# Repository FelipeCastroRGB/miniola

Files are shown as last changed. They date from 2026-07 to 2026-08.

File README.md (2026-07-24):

# Miniola 

A **Miniola** é um projeto de código aberto focado no desenvolvimento de um dispositivo de baixo custo para a inspeção de películas cinematográficas. Utilizando um sistema de transporte contínuo *sprocketless* (sem roletes dentados), o projeto tem como objetivo fornecer subsídios para a preservação do patrimônio audiovisual. Sua criação nasce da vontade de facilitar o acesso ao conteúdo de filmes em película para pesquisadores e arquivistas, além de disponibilizar um conjunto de ferramentas analíticas voltadas à compreensão do estado de conservação dos materiais.

Concebido para ser acessível e modular, o projeto possui uma estrutura cujas peças fundamentais são desenhadas para fabricação em impressoras 3D pequenas e de baixo custo. Além disso, o sistema foi pensado para atender a diferentes realidades, operando sem dependência de um hardware específico e suportando requisitos computacionais flexíveis, bem como câmeras com variadas configurações.

Estado atual de testes de hardware: 

**SBCs e PCs**

- Raspberry Pi 4 (1 GB)
- Raspberry Pi 5 (2 GB)
- Mac Mini 2012 (8 GB) - Linus Mint

**Câmeras**

- Raspberry Pi Camera Module 3
- Raspberry Pi Camera Module 2
- Raspberry Pi Camera Module 1.3
- XIMEA MQ042MG-CM

---

## Estrutura do repositorio

Arquivos principais agora ficam na **raiz do repositorio**:

- `miniola.py`: ponto de entrada principal.
- `process.py`: pos-processamento (gera MP4/ProRes a partir dos frames).
- `miniola_debug.py`: variante de depuracao (opcional)
- `requirements.txt`: dependencias Python.

---

## Guia de instalação

### 1) Dependências de Sistema

O Miniola compila extensões C++ nativas (`miniola_cv`) e utiliza o **FFMPEG** para montagem final de vídeo sincronizado com áudio (`process.py`). Em qualquer plataforma Linux (**x86_64** ou **arm64**), instale os pacotes obrigatórios:

```bash
sudo apt update
sudo apt install -y libcap-dev libgnutls28-dev python3-libcamera git python3-dev python3-venv build-essential ffmpeg libopencv-dev pkg-config
```

### 2) Clonagem

```bash
git clone https://github.com/FelipeCastroRGB/miniola.git
cd ~/miniola
```

### 3) Criação dos Diretórios de Captura

O Miniola precisa de pastas específicas para salvar os quadros temporários e os vídeos processados:
```bash
mkdir -p ~/miniola/capturas
mkdir -p ~/miniola/output
```

### 4) Ambiente Python

```bash
python3 -m venv --system-site-packages venv
source venv/bin/activate
pip install --upgrade pip setuptools wheel
pip install -r requirements.txt
pip install .
```

### 5) Instalação Específica da Câmera

O Miniola suporta diferentes modelos de câmera, com flexibilidade de hardware. Após instalar as dependências base, escolha e instale a opção de câmera que você for utilizar:

#### Opção A: Câmera Ximea (MQ042MG-CM)
Se o scanner utilizar a câmera industrial Ximea, instale o SDK oficial da fabricante (`ximea_api`). Como o pacote difere entre processadores ARM e Intel/AMD (x86_64), escolha o comando correto para a sua máquina:

- **Linux x86_64**:
> *Nota: Se o link principal de download (`kb.ximea.com`) der erro de rota/firewall, acesse a página oficial de downloads (`https://www.ximea.com/support/wiki/apis/XIMEA_Linux_Software_Package`) pelo navegador e baixe o arquivo `XIMEA_Linux_SP.tgz` para a pasta do projeto.*
```bash
# Ou via terminal tentando o servidor de atualizações beta x64:
wget -O XIMEA_Linux_SP.tgz https://updates.ximea.com/public/ximea_linux_x64_sp_beta.tgz || wget -O XIMEA_Linux_SP.tgz https://updates.ximea.com/public/ximea_linux_sp_beta.tgz
tar -xzf XIMEA_Linux_SP.tgz
cd package && ./install -cam_usb30
```

- **Linux arm64 (Raspberry Pi)**:
```bash
wget -O XIMEA_Linux_SP.tgz https://updates.ximea.com/public/ximea_linux_arm_sp_beta.tgz
tar -xzf XIMEA_Linux_SP.tgz
cd package && ./install -cam_usb30
```

#### Opção B: Raspberry Pi Camera Module 3
Se você estiver utilizando a câmera padrão do ecossistema Raspberry Pi, instale as dependências correspondentes:
```bash
pip install picamera2 python-prctl
```
> **IMPORTANTE: Aumento do Buffer USB (Obrigatório para Ximea)**
> Para que a câmera atinja a taxa máxima de quadros (FPS) em USB 3.0 sem engasgos ou perda de pacotes, você **deve** aumentar a memória do buffer USB. No Raspberry Pi OS, faça o seguinte:
>
> **Temporário (perde ao reiniciar):**
> ```bash
> echo 1000 | sudo tee /sys/module/usbcore/parameters/usbfs_memory_mb
> ```
>
> **Permanente (Recomendado):**
> Adicione o parâmetro `usbcore.usbfs_memory_mb=1000` ao final da única linha existente no arquivo `/boot/firmware/cmdline.txt`.
> ```bash
> sudo nano /boot/firmware/cmdline.txt
> ```
> *(Após editar e salvar com `Ctrl+O` > `Enter` > `Ctrl+X`, reinicie o sistema).*

### 6) Configuração do RAM Drive para captura (`tmpfs`) - Opcional

> **Nota de Hardware**: No **Raspberry Pi**, esta montagem em `tmpfs` é **muito recomendada** para gravação em cartões MicroSD. Em **MiniPCs ou computadores com SSDs de alta velocidade (NVMe/SATA)**, este passo é **opcional**, já que a gravação direta no disco costuma ser rápida o suficiente.

Se for configurar o RAM drive (`tmpfs`), edite o arquivo `fstab` (`sudo nano /etc/fstab`) e adicione ao final (lembre-se de substituir `SEU_USUARIO` pelo seu usuário real):

```text
tmpfs /home/SEU_USUARIO/miniola/capturas tmpfs defaults,noatime,size=1024M 0 0
```

Aplicar montagem:

```bash
sudo systemctl daemon-reload && sudo mount -a
```

---

## Operação

Para iniciar o sistema, ative o ambiente virtual e execute o script principal:

```bash
source venv/bin/activate
python3 miniola.py
```

---

## Pos-processamento de video (`process.py`)

Exemplos:

```bash
python3 process.py
python3 process.py --format prores
python3 process.py --format both --fps 18
python3 process.py --verify-frames
```

Por padrao, o script tenta ler frames em:

1. `./capturas`
2. `./captura` (fallback legado)

As saidas e relatorios sao gravados em `./output`.

---

## Nota de manutencao

**Resiliencia headless:** foi implementado um mock para `sys.modules["pykms"]` no topo do `miniola.py`, evitando `ModuleNotFoundError` em ambientes sem monitor fisico no Raspberry Pi OS (Bookworm).

**Fallback de motor de visao:** se `miniola_cv` falhar na compilacao (por ex., dependencias nativas ausentes), o `miniola.py` entra automaticamente em modo Python nativo. O sistema funciona, porem com menor desempenho de processamento.

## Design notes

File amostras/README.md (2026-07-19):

# Amostras e Banco de Dados Visual (`amostras/`)

Este diretório abriga o **banco de dados de imagens e fotogramas reais de película 35mm** que serve como *Ground Truth Visual* e massa de dados para testes unitários, calibração algorítmica e simulação do scanner em PC/Mac sem hardware conectado (`--camera mock`).

---

## Estrutura do Diretório

```text
amostras/
├── README.md                   # Este catálogo e guia
├── 000-template-metadata.json  # Modelo de metadados sidecar para cada imagem (.json)
├── fotogramas/                 # Quadros isolados de imagem + perfuração (PNG/JPG)
└── audio_optico/               # Amostras focadas em pistas de áudio (Densidade/Área Variável)
```

---

## O Poder dos Metadados Sidecar (`.json`) no SDD

Para que uma imagem em `amostras/fotogramas/filmcolors_1935_technicolor_01.png` seja mais do que apenas uma foto, ela deve ser acompanhada de um arquivo sidecar com o **mesmo nome e extensão `.json`** (ex.: `amostras/fotogramas/filmcolors_1935_technicolor_01.json`).

Esse JSON descreve as propriedades físicas da película original (bitola, encolhimento, tipo de áudio, estado de conservação) e, principalmente, as **coordenadas de Ground Truth (`cv_ground_truth`) para verificação automática no nosso motor C++ (`miniola_cv.cpp`) e nos testes (`tests/`)**!

---

## Catálogo de Amostras Ativas

| ID | Arquivo de Imagem | Origem / Acervo | Bitola / Furos | Áudio Óptico | Encolhimento |
| :--- | :--- | :--- | :--- | :--- | :--- |
| *(Exemplo)* `SMP-001` | `fotogramas/kodak_ks_padrao_01.png` | Teste Bancada Miniola | 35mm KS (4 furos) | Densidade Variável | 0.0% |

> **Como Alimentar**: Ao baixar exemplos de sites de referência (como o [FilmColors](https://filmcolors.org/)), escaneamentos próprios ou fotogramas de acervos parceiros, salve a imagem em `fotogramas/` e crie o `.json` correspondente usando `000-template-metadata.json`.

---

## Integração com o Driver Mock e CI
Quando o desenvolvedor executa no Mac Mini ou PC Linux:
```bash
python3 miniola.py --camera mock --sample fotogramas/filmcolors_1935_technicolor_01.png
```
O provedor `MockCameraProvider` carrega a imagem, lê o sidecar `.json`, ajusta automaticamente a ROI e transmite o fotograma em loop no dashboard Flask, permitindo validar o comportamento de detecção de perfurações e alertas *Zebra* em condições idênticas a um rolo real rodando no scanner!

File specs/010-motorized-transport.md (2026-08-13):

# SPEC-010: Integração de Transporte Motorizado (SKR Pico / TMC2209)

| Metadado | Valor |
| :--- | :--- |
| **ID da Especificação** | `SPEC-010` |
| **Status** | `Draft` |
| **Autor** | Antigravity (IA) |
| **Data de Criação** | 2026-07-26 |
| **Última Atualização** | 2026-07-26 |

---

## 1. Contexto e Objetivo
O Miniola atualmente atua como um sistema de captura passivo ou sincronizado manualmente. Para automatizar o processo de digitalização de película e garantir uma tração suave, constante e tracionada com precisão, o sistema requer a integração de um transporte motorizado. 
O hardware escolhido é a placa **BTT SKR PICO V1.0** (baseada no microcontrolador RP2040) em conjunto com drivers **TMC2209** integrados, controlando 2 motores de passo **NEMA 17 (42BYGH23-A-21DH)** para os rolos de filme, e **1 motor de passo 28BYJ-48 (modificado para bipolar)** atuando no eixo Z para controle de foco da câmera.
O objetivo desta especificação é definir como o Miniola se comunicará com esta placa via USB para controlar a velocidade e direção dos motores (X, Y e Z), mantendo a compatibilidade multi-plataforma e sem onerar a CPU que processa a visão computacional.

## 2. Requisitos Funcionais (O que o sistema deve fazer)
- `[RF-01]`: O sistema deve ser capaz de enviar comandos de Iniciar, Parar, Avançar, Recuar e Definir Velocidade para a placa controladora via porta serial (USB).
- `[RF-02]`: O dashboard web do Miniola (`miniola.py`) deve expor controles de interface (botões e sliders) para o transporte motorizado.
- `[RF-03]`: A comunicação serial deve ser não-bloqueante para evitar atrasos no loop principal de captura de quadros.
- `[RF-04]`: O sistema deve permitir a configuração da porta serial (`/dev/tty*` ou COM) via linha de comando ou arquivo de configuração.

## 3. Requisitos Não-Funcionais e Performance
- `[RNF-01]`: A taxa de captura do sensor (`fps_cam`) não deve ser afetada pela comunicação com os motores. O envio de comandos deve ocorrer em uma thread ou processo separado (ou via chamadas assíncronas de baixo custo).
- `[RNF-02]`: A placa controladora deve garantir a precisão dos pulsos (steps) em hardware real-time (no RP2040), garantindo tração suave e operação silenciosa (StealthChop no TMC2209).

---

## 4. Matriz de Impacto Multi-Plataforma

Descreva o comportamento e as restrições em cada perfil de hardware suportado pelo Miniola:

| Plataforma | Comportamento Esperado / Restrições Específicas |
| :--- | :--- |
| **Raspberry Pi 5/4 (`arm64`)** | Conexão USB-C nativa ou via GPIO UART. A porta padrão será tipicamente `/dev/ttyACM0` ou `/dev/ttyUSB0`. Mantém-se o paradigma de gravação em `tmpfs`. |
| **Mac Mini / MiniPCs (`x86_64`)** | Conexão exclusivamente via USB. A porta padrão será algo como `/dev/tty.usbmodem*` (macOS) ou `/dev/ttyACM0` (Linux). Nenhuma diferença no código lógico de controle, apenas o nome da porta. |

---

## 5. Arquitetura e Design Técnico

### 5.1. Componentes e Arquivos Modificados
- `core/motor_controller.py` **[NOVO]**: Módulo em Python responsável por instanciar a comunicação Serial e expor métodos de alto nível (`start()`, `stop()`, `set_speed()`).
- `miniola.py`: Instanciará o `motor_controller` e o passará (ou invocará) a partir do servidor web/dashboard, e conectará os endpoints da API web aos comandos do motor.
- `templates/` e `web/`: Inclusão de botões "Transporte" (Avançar/Recuar, Stop, Slider de Velocidade) no Dashboard (interface web).
- **Firmware da Placa**: A SKR Pico V1.0 rodará um firmware **C++ customizado**. Este firmware receberá comandos seriais simples via UART (via cabo USB-C) do host (RPi ou PC) e traduzirá esses comandos em sinais STEP/DIR para os drivers TMC2209 no microcontrolador RP2040 em tempo real. Adicionalmente, o firmware fará a leitura de um **Encoder Rotativo E38S6G5-600B-G24N (sinal NPN)** diretamente conectado aos seus pinos GPIO, e reportará a contagem de pulsos (posição) via porta serial de volta ao host.

### 5.2. Contratos e Estruturas de Dados

```python
# Contrato sugerido para o motor_controller.py
class MotorController:
    def __init__(self, port: str, baudrate: int = 115200):
        pass

    def connect(self) -> bool:
        pass

    def disconnect(self):
        pass

    def move_forward(self, speed: float):
        """ speed em mm/s ou rpm """
        pass

    def move_backward(self, speed: float):
        pass

    def stop(self):
        pass
```

---

## 6. Critérios de Aceitação e Plano de Verificação

### 6.1. Verificação Automatizada / Bancada (`tests/`)
- [ ] O teste unitário `test_motor_controller.py` deve mockar a porta serial e verificar se os comandos corretos (ex: strings G-code ou protocolo binário) são enviados para o buffer.
- [ ] A checagem `python3 scripts/check_specs.py` não deve apontar erros nesta spec.

### 6.2. Verificação Manual / Hardware
- [ ] Conectar a SKR Pico via USB e verificar se o Miniola consegue abrir a porta serial sem crashar.
- [ ] Clicar no botão "Avançar" no Dashboard e confirmar se o comando é transmitido e os NEMA 17 giram sem afetar o FPS da câmera.

---

## 7. Fase 2: Controle Duplo e Dinâmica de Rolos (Tração Direta)

Na Fase 2, o sistema passará a controlar 2 motores (Feed-in e Take-up) cujas velocidades físicas mudam constantemente devido à variação do diâmetro dos rolos de filme. A arquitetura escolhida (Opção A) define que:

### 7.1. Medição de Velocidade via Encoder
O hardware utilizará um **Encoder Rotativo E38S6G5-600B-G24N (600 PPR)** acoplado a um rolete por onde o filme passa. O rolete tem um **diâmetro de 26.6 mm**. O firmware da SKR Pico fará a contagem dos pulsos (usando interrupções rápidas via PIO/registradores no pino de UART) e o módulo Python converterá para velocidade linear (mm/s) através da fórmula:
`Velocidade (mm/s) = (Pulsos_Lidos / 600) * (PI * 26.6) / Tempo_Decorrido`
*Nota: Qualquer acoplamento anterior do cálculo de velocidade com a Visão Computacional (OpenCV) foi **completamente removido** da malha mecânica. Conforme definido na **SPEC-011**, a responsabilidade da velocidade é 100% do Encoder físico.*

### 7.2. Malha de Controle (PID) em Python e Aceleração (S-Curve)
A "mola matemática" será implementada em Python. O módulo `motor_controller.py` implementará um loop PID (Proporcional-Integral-Derivativo) **estritamente isolado da ótica**. Utilizando a velocidade linear calculada pelo encoder como Variável de Processo (PV). 

A velocidade alvo (Setpoint) durante a Gravação (REC) será derivada diretamente da variável global `fps_motor` (configurada via comando `mfps` no terminal), convertida para mm/s. O "sistema de playback" (sincronia estrita via `FPS_PROJECAO`) está temporariamente desabilitado para privilegiar a cadência e tração contínua da película, e a captura da câmera (`fps_cam`) agora roda totalmente desacoplada da velocidade física dos rolos.

**Aceleração (Soft Start):** Para evitar solavancos e o rompimento do filme no momento de ligar os motores, a meta do PID não sobe subitamente (degrau). Ela passa por uma rampa matemática (Smoothstep / S-Curve) durante os primeiros N segundos da captura, garantindo um "Ease-In" mecânico liso. Ao comparar com a velocidade desejada real-time, o PID ajustará a velocidade dos motores enviando comandos diferenciais (F) via porta serial para compensar o enchimento/esvaziamento dos rolos.

### 7.3. Tensão de Emergência (StallGuard)
O firmware C++ da SKR Pico fará a leitura constante do *StallGuard 4* (sensor de carga mecânica sem sensor embutido nos drivers TMC2209) medindo o *back-EMF*. Caso o filme enrosque, o pico de tensão mecânica será detectado instantaneamente pelo firmware, que cortará a corrente dos motores (emergência) e notificará o host via USB, protegendo a película de rompimento.

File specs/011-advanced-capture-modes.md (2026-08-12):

# SPEC-011: Modos de Captura Avançados (Telecine Híbrido)

| Metadado | Valor |
| :--- | :--- |
| **ID da Especificação** | `SPEC-011` |
| **Status** | `Draft` |
| **Autor** | Antigravity (IA) |
| **Data de Criação** | 2026-08-08 |
| **Última Atualização** | 2026-08-08 |

---

## 1. Contexto e Objetivo
Historicamente, a Miniola dependia da Visão Computacional (CV) tanto para o alinhamento óptico quanto para determinar a velocidade do transporte. Essa dependência ("Tight Coupling") causava instabilidades mecânicas sempre que a CV perdia um quadro.
Com a integração do Encoder Rotativo (SPEC-010), o sistema ganha consciência posicional absoluta. O objetivo desta especificação é definir a arquitetura do **Modo Telecine Contínuo Híbrido**, que separa as responsabilidades entre Mecânica (Velocidade) e Óptica (Fase/Alinhamento), criando um sistema resiliente a filmes danificados e encolhidos.

## 2. A Arquitetura Híbrida (Desacoplada)

A solução baseia-se na separação estrita de domínios:

### 2.1. O Domínio Mecânico (Estabilidade de Velocidade)
- O transporte do filme é governado **exclusivamente** pelo Encoder físico através da malha PID em `core/motor_controller.py`.
- O PID ignora sumariamente o que a câmera "enxerga", garantindo uma tração suave (efeito flywheel/volante de inércia) independente do estado físico das perfurações do filme.
- O Encoder fornece a métrica de `current_mm_s`.

### 2.2. O Domínio Óptico (Estabilidade de Fase e Alinhamento)
- A câmera roda em modo "Oversampling" (alta taxa de quadros, ex: 120 fps) com luz contínua.
- O motor C++ (`miniola_cv.cpp`) atua **exclusivamente** como um extrator de quadros (Frame Picker).
- Ao detectar a linha exata da perfuração, o C++ seleciona aquele quadro perfeito e o extrai, descartando os intermediários (borrados ou fora de esquadro).
- Isso garante imunidade ao "Encolhimento do Filme" (Shrinkage), pois o sistema fotografa o que realmente está na janela (Optical Registration) em vez de confiar cegamente na matemática do encoder que falha se o filme estiver encolhido.

### 2.3. Interpolação de Software (Dead-Reckoning)
- Caso o OpenCV sofra um "dropframe" ou uma perfuração esteja completamente rasgada, o software python injetará a "Previsão" baseada no Encoder.
- Se o filme avançar o equivalente a 1 frame (ex: 4.75mm para 35mm) sem que o OpenCV tenha reportado sucesso, o sistema força a gravação do quadro naquele momento exato, usando a medição física do encoder como fallback. Isso impede a "perda de sincronia".

### 2.4. Modo Playback PLL (Phase-Locked Loop Inverso)
- Para garantir o visionamento em tempo real (ex: 24 fps) sem instabilidades, a lógica mestre-escravo é invertida.
- A **Câmera atua como Mestre**: Roda continuamente a uma taxa de quadros fixa (ex: 24.0 fps) gerada pelo seu próprio relógio (Free Run).
- O **Motor atua como Escravo**: O PID do `motor_controller.py` tenta manter a velocidade em 24 fps e usa a informação do OpenCV como "Erro de Fase".
- A cada quadro, o OpenCV verifica se a perfuração está acima ou abaixo da `LINHA_GATILHO_Y`. Esse desvio em pixels é convertido para milímetros e injetado no PID como correção de fase (`update_phase_error()`), forçando o motor a acelerar ou frear sutilmente para travar a perfuração no centro da câmera.

## 3. Modificações de Arquivos Associadas
- `core/motor_controller.py`: Eliminação do `notify_perforation` como variável do PID. Adoção da lógica de interpolação.
- `src/miniola_cv.cpp`: O FPS meter acoplado ao gatilho é desabilitado. O OpenCV apenas carimba o quadro atual (Timestamps e Flags) e manda para a fila de gravação `process.py`.
- `miniola.py`: Orquestra o fluxo de gravação contínuo mesclando as informações do Encoder com o evento do OpenCV.

## 4. Requisitos Futuros (Roadmap)
- **Modo Roda-Livre:** Implementação de botão no Dashboard que corta a corrente dos motores TMC2209 (`EN=1`) permitindo manipulação manual.
- **Modo Scanner (Stop-Motion RGB):** Captura passo-a-passo (4 perfurações -> para -> fotos -> avança) para digitalização com câmera monocromática e luzes RGB.

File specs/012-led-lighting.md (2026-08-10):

# SPEC-012: Controle de Iluminação LED (Painel) via SKR Pico

| Metadado | Valor |
| :--- | :--- |
| **ID da Especificação** | `SPEC-012` |
| **Status** | `Draft` |
| **Autor** | Antigravity (IA) |
| **Data de Criação** | 2026-08-09 |
| **Última Atualização** | 2026-08-09 |

---

## 1. Contexto e Objetivo
Para realizar a digitalização dos fotogramas, o Miniola necessita de uma fonte de iluminação (Painel LED) para projetar a luz através da película. Em vez de utilizar uma fonte de alimentação externa sem controle de software, o objetivo é ligar o painel LED diretamente a uma das portas de potência da controladora BTT SKR Pico (ex: porta do cartucho de aquecimento HE0) e usar o sinal PWM da placa para dimerizar a intensidade de luz.

## 2. Requisitos Funcionais (O que o sistema deve fazer)
- `[RF-01]`: O firmware C++ da SKR Pico deve receber o comando serial `L <valor>` (de 0 a 255) para alterar o PWM da porta de potência, ajustando o brilho do LED.
- `[RF-02]`: A interface Web (Dashboard) deverá ter um controle deslizante (slider) para ajustar o nível da iluminação em tempo real.
- `[RF-03]`: A biblioteca `motor_controller.py` deve abstrair a conversão do comando e o envio via Serial.

## 3. Requisitos Não-Funcionais e Performance
- `[RNF-01]`: O envio de comandos de LED não deve engasgar a leitura do encoder nem a velocidade de processamento das perfurações.

---

## 4. Matriz de Impacto Multi-Plataforma

| Plataforma | Comportamento Esperado / Restrições Específicas |
| :--- | :--- |
| **Todas** | Comunicação Serial já abstrata. Independente de OS. |

---

## 5. Arquitetura e Design Técnico

### 5.1. Componentes Modificados
- `firmware/src/main.cpp`: Inclusão do `#define LED_PIN 23` (Porta de Heater 0, suporta até ~5A, ideal para o painel LED) e parse do comando `L`.
- `core/motor_controller.py`: Novo método `set_led_brightness(self, level)`.
- `web/routes.py`: Nova rota `/api/set_light` que recebe POST ou GET e repassa ao MotorController.
- `templates/index.html`: Novo Slider na UI para controle interativo.

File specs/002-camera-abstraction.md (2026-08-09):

# SPEC-002: Camada de Abstração de Câmeras (CameraProvider)

| Metadado | Valor |
| :--- | :--- |
| **ID da Especificação** | `SPEC-002` |
| **Status** | `Completed` |
| **Autor** | Equipe Miniola |
| **Data de Criação** | 2026-07-19 |
| **Última Atualização** | 2026-07-19 |

---

## 1. Contexto e Objetivo
Para democratizar a preservação audiovisual, o Miniola não pode ficar preso a um único modelo de sensor. Projetos de baixo custo podem utilizar a câmera padrão do ecossistema Raspberry Pi (`Camera Module 3` via `picamera2`), enquanto digitalizações profissionais/industriais utilizam a câmera de alta velocidade Ximea (`MQ042MG-CM` com `ximea_api`). Além disso, para rodar em MiniPCs ou no Mac Mini x86_64, o sistema precisa suportar câmeras industriais genéricas USB/UVC e provedores virtuais de simulação (Mock/Playback).

Esta especificação formaliza a interface abstrata `CameraProvider` (`cameras/base.py`) e o contrato modular dos drivers implementados.

## 2. Requisitos Funcionais
- `[RF-01]`: O sistema deve prover uma função fábrica `get_camera_provider(provider_name: str) -> CameraProvider` em `cameras/__init__.py`.
- `[RF-02]`: Todos os drivers de câmera devem herdar de `CameraProvider` e implementar obrigatoriamente os métodos: `start(...)`, `get_frame() -> np.ndarray`, `set_exposure(...)`, `set_gain(...)`, `set_fps(...)` e `stop()`.
- `[RF-03]`: O método `get_frame()` deve retornar rapidamente (`non-blocking` ou com timeout curto) um quadro RAW ou BGR do tamanho configurado no `start()`.
- `[RF-04]`: O driver `ximea` (`cameras/ximea.py`) deve aplicar crop por hardware (`CAM_OFFSET_X`, `CAM_OFFSET_Y`) diretamente nos registradores do sensor via `xiAPI` para maximizar o frame rate no barramento USB 3.0, ou utilizar negociação automática (`auto_bandwidth_calculation = 1`) com fallback `FREE_RUN` e `timeout=2000` em barramentos xHCI.
- `[RF-05]`: O driver `pi` (`cameras/pi.py`) deve instanciar `Picamera2`, configurar controles manuais (exposição, ganho) e capturar frames contínuos em memória.
- `[RF-06]`: A arquitetura deve permitir registrar novos provedores (como `uvc` e `mock`) dinamicamente para rodar em hardware x86_64 que não possui CSI de Raspberry Pi.

## 3. Requisitos Não-Funcionais e Performance
- `[RNF-01]`: A obtenção do quadro em `get_frame()` deve retornar sem alocar cópias redundantes de memória, EXCETO quando o provedor retornar um ponteiro sobre um buffer C mutável externo (como em `XimeaAdapter`, onde `get_image_data_numpy().copy()` é obrigatório para evitar colisão de concorrência com threads consumidoras do OpenCV/Flask).
- `[RNF-02]`: O tempo entre chamadas sucessivas de `get_frame()` deve ser estável para suportar 120 FPS (`< 8.33 ms` por frame).

---

## 4. Matriz de Impacto Multi-Plataforma

| Plataforma | Provedores Suportados | Restrições / Notas de Operação |
| :--- | :--- | :--- |
| **Raspberry Pi 5/4 (`arm64`)** | `pi`, `ximea`, `mock` | O driver `pi` exige `picamera2` instalado via apt/pip do SO Bookworm. O driver `ximea` exige o aumento permanente do buffer USB (`usbfs_memory_mb=1000`) em `/boot/firmware/cmdline.txt`. |
| **Mac Mini / MiniPCs (`x86_64`)** | `ximea`, `uvc`, `mock` | O driver `pi` não está disponível em sistemas x86_64 sem hardware CSI (o import deve ser graciosamente evitado em `__init__.py` ou retornar erro explicativo se solicitado). A câmera Ximea conecta via USB 3.0 no Linux x86_64 com o pacote `ximea_linux_arm_sp_beta.tgz` (ou versão x86). |

---

## 5. Arquitetura e Design Técnico

### 5.1. Componentes e Arquivos Modificados
- `cameras/base.py`: Define a classe abstrata `CameraProvider`.
- `cameras/ximea.py`: Implementação para câmeras industriais Ximea usando `from ximea import xiapi`.
- `cameras/pi.py`: Implementação para módulos Raspberry Pi usando `from picamera2 import Picamera2`.
- `cameras/__init__.py`: Seletor de provedores `get_camera_provider(provider_name)`.

### 5.2. Contrato da Classe Abstrata (`cameras/base.py`)
```python
class CameraProvider:
    def start(self, width: int, height: int, fps: int, shutter_us: int, gain: float, focus: float, offset_x: int, offset_y: int) -> None:
        raise NotImplementedError
        
    def get_frame(self) -> np.ndarray:
        raise NotImplementedError
        
    def set_exposure(self, shutter_us: int) -> None:
        raise NotImplementedError
        
    def set_gain(self, gain: float) -> None:
        raise NotImplementedError
        
    def set_fps(self, fps: int) -> None:
        raise NotImplementedError
        
    def set_focus(self, focus: float) -> None:
        pass
        
    def set_white_balance(self, kr: float, kg: float, kb: float) -> None:
        pass
        
    def set_gamma(self, gamma_y: float, gamma_c: float) -> None:
        pass
        
    def set_contrast(self, value: float) -> None:
        pass
        
    def set_sharpness(self, value: float) -> None:
        pass
        
    def stop(self) -> None:
        raise NotImplementedError
```

---

## 6. Critérios de Aceitação e Plano de Verificação

### 6.1. Verificação Automatizada (`tests/`)
- [x] O teste de verificação de especificações (`check_specs.py`) confirma a existência e validade do contrato `CameraProvider`.
- [x] A instanciação de provedores mock/sintéticos em `tests/` verifica se `get_frame()` retorna matrizes com as dimensões especificadas (`RES_W, RES_H`).

### 6.2. Verificação Manual / Hardware
- [x] Ao iniciar com `python3 miniola.py --camera ximea` no Raspberry Pi ou MiniPC, a inicialização imprime o modelo da câmera e começa a transmitir quadros no dashboard sem engasgos de buffer USB.

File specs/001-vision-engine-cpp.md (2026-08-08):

# SPEC-001: Motor de Visão Computacional em C++ (miniola_cv)

| Metadado | Valor |
| :--- | :--- |
| **ID da Especificação** | `SPEC-001` |
| **Status** | `Completed` |
| **Autor** | Equipe Miniola |
| **Data de Criação** | 2026-07-19 |
| **Última Atualização** | 2026-07-19 |

---

## 1. Contexto e Objetivo
O Miniola inspeciona filmes cinematográficos de 35mm em alta velocidade. Para capturar quadros sincronizados de forma estável, o sistema analisa a fenda da perfuração em tempo real (120 FPS+). Fazer binarização, busca de contornos e cálculos geométricos complexos em puro Python (NumPy/OpenCV Python) satura o interpretador e derruba a taxa de quadros no Raspberry Pi.

Esta especificação define o comportamento do motor nativo otimizado em C++ (`miniola_cv.cpp`) que se conecta ao Python via `pybind11`, bem como o contrato de fallback em Python puro caso a extensão C++ não esteja compilada.
Conforme estabelecido pela **SPEC-011**, o papel primordial deste módulo passa a ser o de **Extrator de Fase (Frame Picker)**, abandonando a responsabilidade de medir a velocidade do transporte.

## 2. Requisitos Funcionais
- `[RF-01]`: O motor de visão deve recortar a região de interesse (ROI) da perfuração a partir do quadro RAW da câmera.
- `[RF-02]`: O motor deve aplicar threshold de binarização (`THRESH_VAL`) na escala de cinza da ROI reduzida (`ESCALA_CV = 0.5`) para detecção rápida.
- `[RF-03]`: Deve encontrar contornos, filtrar por proporção (`0.2 < w/h < 2.5`) e área (`200 < area < 10000`) para identificar furos válidos de 35mm.
- `[RF-04]`: Deve detectar se uma perfuração cruzou a linha de gatilho Y (`LINHA_GATILHO_Y +- MARGEM_GATILHO`).
- `[RF-05]`: A cada ciclo de 4 perfurações (padrão 35mm = 4 furos por fotograma), o motor deve calcular o centro X e Y do quadro (`cx_a`, `cy_a`), calcular o pitch instantâneo/médio e sinalizar `capturar = True`.
- `[RF-06]`: Deve computar o encolhimento percentual atual do filme (`encolhimento_atual_pct`) comparando o pitch médio com `PITCH_PADRAO_PX`.
- `[RF-07]`: O motor atua estritamente como um Seletor de Fase (Frame Picker). A sinalização de alinhamento (`perfuracao_na_linha`) não deve mais ser usada como entrada para a malha de velocidade PID do motor.

## 3. Requisitos Não-Funcionais e Performance
- `[RNF-01]`: O tempo de execução por quadro (`tempo_ms_ciclo`) na chamada `process_frame` deve ser inferior a 3 ms em Raspberry Pi 5 e inferior a 1 ms em x86_64.
- `[RNF-02]`: A alocação de memória dentro do C++ deve reutilizar buffers estáticos de contorno ou vetores internos, evitando chamadas contínuas de `malloc`/`new`.

---

## 4. Matriz de Impacto Multi-Plataforma

| Plataforma | Comportamento Esperado / Restrições Específicas |
| :--- | :--- |
| **Raspberry Pi 5/4 (`arm64`)** | Compilado via `setup.py` ligando com `/usr/include/opencv4` do sistema Debian Bookworm. Em RPi 4, a resolução do sensor é cortada (`RES_W=1420, RES_H=880`) antes de enviar ao C++ para evitar gargalo USB. |
| **Mac Mini / MiniPCs (`x86_64`)** | Compilado via `setup.py` usando `pkg-config opencv4`. Aproveita otimizações nativas de CPU Intel/AMD, permitindo processar a resolução integral ou matrizes maiores com latência praticamente zero. |

---

## 5. Arquitetura e Design Técnico

### 5.1. Componentes e Arquivos Modificados
- `src/miniola_cv.cpp`: Módulo C++ com a classe `ScannerVision` exportada via `pybind11`.
- `setup.py`: Script de build `build_ext` configurado para buscar flags e bibliotecas do OpenCV via `pkgconfig` ou fallback padrão.
- `miniola.py`: Importação com bloco `try/except ImportError` para definir `CV_ENGINE = "C++ [Pybind11]"` ou `"Python [Nativo]"`.

### 5.2. Contrato da API (`pybind11`)
```python
class ScannerVision:
    def __init__(self) -> None: ...
    def reset_ciclo(self) -> None: ...
    def process_frame(
        self,
        frame_raw: np.ndarray,
        lx: int, ly: int, lw: int, lh: int,
        thresh_val: int, linha_gatilho_y: int, margem_gatilho: int,
        pitch_padrao_px: float,
        capturar_audio: bool, audio_x: int, audio_w: int, slit_y: int
    ) -> dict: ...
```
O dicionário de retorno do `process_frame` deve conter:
- `capturar`: `bool`
- `achou_furo`: `bool`
- `perfuracao_na_linha`: `bool`
- `contador_perfs_ciclo`: `int`
- `cx_a`, `cy_a`: `int` (coordenadas globais para o centro do fotograma)
- `encolhimento_atual_pct`: `float`
- `ultimo_pitch_medio`: `float`
- `pitch_instantaneo`: `float`
- `binary_small`: `np.ndarray` (imagem binarizada para o dashboard)
- `debug_visual`: `list[dict]` (retângulos com coordenadas e cores dos furos detectados)
- `audio_chunk`: `np.ndarray` (amostra de áudio extraída, se `capturar_audio` ativo)

---

## 6. Critérios de Aceitação e Plano de Verificação

### 6.1. Verificação Automatizada (`tests/`)
- [x] O módulo C++ compila com sucesso executando `python3 setup.py build_ext --inplace`.
- [x] O teste de bancada `test_vision_engine.py` passa ao processar quadros sintéticos simulando 4 perfurações sequenciais, validando que o gatilho dispara no 4º furo.

### 6.2. Verificação em Hardware / Operação
- [x] Ao alternar o comando `motor` no painel do `miniola.py`, o sistema transita entre C++ e Python sem travar e relatando o motor no cabeçalho do painel.

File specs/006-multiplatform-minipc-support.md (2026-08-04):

# SPEC-006: Suporte Multi-Plataforma para MiniPCs e Mac Mini (`x86_64` Linux)

| Metadado | Valor |
| :--- | :--- |
| **ID da Especificação** | `SPEC-006` |
| **Status** | `Completed` |
| **Autor** | Equipe Miniola |
| **Data de Criação** | 2026-07-19 |
| **Última Atualização** | 2026-07-19 |

---

## 1. Contexto e Objetivo
O Miniola nasceu rodando no Raspberry Pi 5 e 4. Embora o Raspberry Pi 5 seja excelente e compacto, existem cenários onde o usuário ou instituição arquivística já possui computadores compactos potentes — rodando Linux (`x86_64`), Intel NUCs ou MiniPCs industriais com portas USB 3.0 rápidas e discos SSD internos.

Rodar em um MiniPC x86_64 sem modificações manuais elimina a dependência exclusiva de placas Raspberry Pi, aumenta a folga de memória RAM (8GB a 16GB+) e de processamento multicore, e permite conectar câmeras Ximea por USB 3.0 ou câmeras genéricas UVC / arquivos de simulação (Mock Playback) para testes e digitalização na bancada do usuário.

Esta é a **primeira especificação estrutural e evolutiva do nosso fluxo de Spec-Driven Development (SDD)**, estabelecendo a camada de abstração de plataforma (HAL) no Miniola.

## 2. Requisitos Funcionais
- `[RF-01]`: O sistema deve detectar a arquitetura host (`platform.machine()`) no topo do `miniola.py` para aplicar automaticamente o perfil de hardware apropriado (`arm64`/`aarch64` vs. `x86_64`).
- `[RF-02]`: O mock de subsistemas de vídeo headless exclusivos do Raspberry Pi (`sys.modules["pykms"] = MagicMock()`) deve ser isolado com segurança para não gerar conflitos com drivers de vídeo ou ambientes de janela no Linux x86_64.
- `[RF-03]`: A leitura térmica na rota `/status` deve verificar dinamicamente a presença de sensores térmicos do host (tentando `/sys/class/thermal/thermal_zone0/temp` ou paths genéricos do kernel Linux x86_64) sem falhar se o arquivo não existir (`try/except` robusto retornando `0.0`).
- `[RF-04]`: O sistema deve suportar provedores de câmera adicionais em `cameras/`:
  - Provedor `uvc` (`cameras/uvc.py` ou integrado no seletor) usando `cv2.VideoCapture` com controle UVC padrão via OpenCV, permitindo que qualquer webcam ou câmera industrial UVC USB 3.0 funcione no Mac Mini.
  - Provedor `mock` (`cameras/mock.py`) que gera quadros sintéticos ou lê um arquivo de vídeo/imagem (`playback`) para permitir que o desenvolvedor execute, teste o gatilho e altere especificações no PC local sem nenhum hardware de scanner conectado.
- `[RF-05]`: O comando de desligamento (`off`) no painel deve checar permissões ou utilizar chamadas genéricas de encerramento (`sudo poweroff` / `systemctl poweroff`) compatíveis com distribuições Debian/Ubuntu em x86_64.

## 3. Requisitos Não-Funcionais e Performance
- `[RNF-01]`: O suporte x86_64 não deve introduzir nenhum overhead computacional ou checagem de plataforma repetitiva dentro do loop crítico de visão ou no método `process_frame`. A detecção e configuração do perfil de hardware devem ocorrer uma única vez na inicialização do script.
- `[RNF-02]`: A compilação da extensão C++ (`setup.py`) deve funcionar de forma perfeitamente transparente e nativa tanto com `gcc`/`g++` em `arm64` quanto em `x86_64`.

---

## 4. Matriz de Impacto Multi-Plataforma

| Plataforma | Ações e Comportamentos do Perfil |
| :--- | :--- |
| **Raspberry Pi 5/4 (`arm64` / `aarch64`)** | Perfil `rpi`: Ativa mock de `pykms` em ambiente sem monitor, restringe buffer de processamento para aliviar USB 3.0 em modelos RPi 4, e utiliza o provedor `pi` (`picamera2`) como alternativa ao `ximea`. |
| **Mac Mini / MiniPCs (`x86_64`)** | Perfil `minipc_x86_64`: Pula inicializações exclusivas do ecossistema Pi (`picamera2`), ativa suporte nativo ao SDK Ximea Linux para arquitetura x86_64 ou câmeras `uvc`/`mock`. Em controladoras USB 3.0 xHCI (ex: Mac Mini Late 2012 com processador Ivy Bridge), a largura de banda do sensor Ximea deve usar negociação dinâmica (`auto_bandwidth_calculation=1`) e o `processo_escrita_disco` deve usar obrigatoriamente gravação nativa C++ `cv2.imwrite` com libjpeg-turbo, evitando gargalos de I/O na CPU/USB durante capturas com `REC` ativo. Requer `ffmpeg` instalado via `apt` para compilação final em `process.py`. |

---

## 5. Arquitetura e Design Técnico

### 5.1. Componentes e Arquivos Modificados
- `miniola.py`: Inclusão de verificação de arquitetura com `import platform`, tratamento seguro em `/status` para sensores térmicos x86_64 e expansão dos argumentos de `--camera` (`choices=['pi', 'ximea', 'uvc', 'mock']`).
- `cameras/__init__.py`: Seletor modular que carrega `ximea`, `pi` (somente em ARM ou com tratamento de import), `uvc` e `mock`.
- `cameras/mock.py`: Implementação da classe `MockCameraProvider` herdando de `CameraProvider` (gera quadros com 4 perfurações simuladas e fenda de som para testes contínuos de SDD).

### 5.2. Estrutura do Perfil de Hardware (Exemplo Lógico em `miniola.py`)
```python
import platform

ARQUITETURA_HOST = platform.machine().lower()
IS_RPI = "arm" in ARQUITETURA_HOST or "aarch64" in ARQUITETURA_HOST

if IS_RPI:
    # Ajustes exclusivos de Raspberry Pi
    sys.modules["pykms"] = MagicMock()
    sys.modules["kms"] = MagicMock()
```

---

## 6. Critérios de Aceitação e Plano de Verificação

### 6.1. Verificação Automatizada (`tests/`)
- [x] A suíte de testes em `tests/` pode rodar nativamente em qualquer Linux x86_64 ou Mac Mini, instanciando o provedor `mock` e validando o pipeline de visão em C++ (`miniola_cv.cpp`).
- [x] O valider `check_specs.py` confirma a especificação SPEC-006 e suas métricas.

### 6.2. Verificação Operacional no Mac Mini / MiniPC
- [x] Executar `python3 miniola.py --camera mock` no Linux x86_64 inicia o servidor Flask sem erros de `pykms` ou `Picamera2`, permitindo abrir o dashboard no navegador, ajustar o crop via web e simular gravações assíncronas.

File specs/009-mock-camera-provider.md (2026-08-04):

# SPEC-009: Provedor Mock de Câmera (`mock`)

| Metadado | Valor |
| :--- | :--- |
| **ID da Especificação** | `SPEC-009` |
| **Status** | `Completed` |
| **Autor** | Equipe Miniola |
| **Data de Criação** | 2026-07-23 |
| **Última Atualização** | 2026-07-23 |

---

## 1. Contexto e Objetivo
Para possibilitar o desenvolvimento, teste e validação de rotas, gravação assíncrona e gatilhos de visão em computadores de desenvolvimento (x86_64) sem a necessidade de hardware conectado, o sistema necessita de um provedor de câmera simulado (`mock`). 
Este provedor atende ao princípio de desenvolvimento multi-plataforma e reduz o atrito para testar a interface e a lógica central do motor.

## 2. Requisitos Funcionais
- `[RF-01]`: O provedor deve herdar de `CameraProvider`.
- `[RF-02]`: O modo sintético deve gerar frames contínuos a 120 FPS que simulem uma película em movimento, contendo perfurações animadas (retângulos brancos se deslocando na vertical) e uma fenda de áudio, permitindo o engajamento do algoritmo C++ (`miniola_cv`).
- `[RF-03]`: Se fornecido um caminho de vídeo (playback) na inicialização ou via variável de ambiente, o provedor deve extrair os frames desse vídeo iterativamente, fazendo loop ao final.
- `[RF-04]`: O provedor **não deve operar em sistemas ARM64** (Raspberry Pi), para evitar consumo desnecessário de CPU com geração de frames falsos em um ambiente de produção/captura. O instanciamento deve lançar erro ou ser prevenido.

## 3. Requisitos Não-Funcionais e Performance
- `[RNF-01]`: A geração de quadros sintéticos deve ser otimizada (usando arrays numpy pré-alocados ou operações rápidas) para manter os 120 FPS na máquina de desenvolvimento.
- `[RNF-02]`: O mock deve implementar todos os métodos da interface (ex: `set_exposure`, `set_gain`, etc) de forma "no-op" (sem fazer nada, ou apenas registrando o valor).

---

## 4. Matriz de Impacto Multi-Plataforma

| Plataforma | Comportamento Esperado / Restrições Específicas |
| :--- | :--- |
| **Raspberry Pi 5/4 (`arm64`)** | Não suportado. O instanciamento falhará intencionalmente com `RuntimeError` ou similar. |
| **Mac Mini / MiniPCs (`x86_64`)** | Suportado nativamente. Funciona como principal ferramenta de simulação de hardware (SDD). |

---

## 5. Arquitetura e Design Técnico

### 5.1. Componentes e Arquivos Modificados
- `cameras/mock.py`: Implementa `MockCameraProvider`. Gera quadros pretos com elementos brancos dinâmicos usando `numpy` e `cv2`. Mantém o tempo com `time.sleep` ou controle de loop para não ultrapassar 120 FPS.
- `cameras/__init__.py`: Importa e retorna a instância de `MockCameraProvider` se a plataforma não for `arm64` / `aarch64`.

### 5.2. Contratos e Estruturas de Dados
```python
class MockCameraProvider(CameraProvider):
    def __init__(self, video_path: str = None):
        ...
```

---

## 6. Critérios de Aceitação e Plano de Verificação

### 6.1. Verificação Automatizada / Bancada (`tests/`)
- [ ] O script `check_specs.py` não aponta erros.

### 6.2. Verificação Manual / Hardware
- [ ] Ao iniciar com `--camera mock` num x86_64, a UI mostra quadros em movimento e mantém ~120 FPS.
- [ ] Se tentar iniciar com `--camera mock` num RPi, ocorre um log/falha clara sobre arquitetura não suportada.

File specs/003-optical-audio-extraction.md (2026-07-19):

# SPEC-003: Extração e Síntese de Áudio Óptico (Captura ao Vivo e Pós-Processamento)

| Metadado | Valor |
| :--- | :--- |
| **ID da Especificação** | `SPEC-003` |
| **Status** | `Completed` |
| **Autor** | Equipe Miniola |
| **Data de Criação** | 2026-07-19 |
| **Última Atualização** | 2026-07-19 |

---

## 1. Contexto e Objetivo
O filme de 35mm frequentemente carrega uma pista de som óptico (densidade variável ou área variável) na lateral adjacente às perfurações. Para preservar o som junto com a imagem sem precisar de um cabeçote magnético ou leitor laser dedicado, o Miniola captura amostras visuais de luminância da pista de áudio a cada quadro em alta velocidade e, no pós-processamento, reconstrói o sinal de áudio digital sincronizado em arquivo WAV.

Esta especificação define o pipeline de extração de som ao vivo (geração do sidecar `.f32` + metadados `.json`) no `miniola.py`/`miniola_cv.cpp` e a síntese/alinhamento em `process.py`.

## 2. Requisitos Funcionais
- `[RF-01]`: O sistema deve definir uma região de extração de áudio na lateral da ROI de perfuração (`AUDIO_X_OFFSET = 50`, `AUDIO_READ_W = 96`).
- `[RF-02]`: Durante a gravação (`GRAVANDO = True`), o motor de visão (em C++) deve extrair as linhas da pista de áudio para cada quadro processado e gerar um pacote `audio_chunk` de luminância.
- `[RF-03]`: Os chunks de áudio extraídos devem ser enviados para a `fila_gravacao` de forma assíncrona com mensagem `{"type": "audio_chunk", "data": chunk}`.
- `[RF-04]`: O processo de gravação deve gerenciar uma sessão de áudio (`abrir_sessao_audio_optico`, `fechar_sessao_audio_optico`) e escrever sequencialmente as amostras brutas de ponto flutuante em `capturas/miniola_audio_{session_id}.f32`.
- `[RF-05]`: Ao encerrar a gravação (`rec_stop`), o sistema deve salvar um arquivo sidecar contendo metadados de sincronismo (`capturas/miniola_audio_{session_id}.json`), incluindo taxa de amostragem calculada com base no FPS de projeção (`fps_projecao`) e no pitch calculado (`samples_per_frame = pitch * 4`).
- `[RF-06]`: No pós-processamento (`process.py --extract-audio`), o script deve ler o `.f32` e `.json`, aplicar processamento de sinal (filtragem de ruído, equalização/normalização) e gerar um arquivo `WAV` sincronizado com o vídeo final na pasta `output/`.

## 3. Requisitos Não-Funcionais e Performance
- `[RNF-01]`: A extração da amostra visual da fenda de áudio no C++ (`miniola_cv.cpp`) deve ser vetorizada pela média das colunas em cada linha horizontal da fenda, operando sem alocação dinâmica contínua.
- `[RNF-02]`: O fluxo contínuo de escrita de chunks no arquivo `.f32` deve ser não-bloqueante no processo isolado do disco, com `flush()` ao final de cada sessão.

---

## 4. Matriz de Impacto Multi-Plataforma

| Plataforma | Comportamento Esperado / Restrições Específicas |
| :--- | :--- |
| **Raspberry Pi 5/4 (`arm64`)** | O processamento em `process.py` utiliza `scipy.signal` e `noisereduce`. No RPi, a filtragem de ruído espectral pesado pode levar alguns segundos por minuto de áudio; o script deve exibir barra de progresso no terminal e evitar consumo excessivo de RAM (processamento em blocos se necessário). |
| **Mac Mini / MiniPCs (`x86_64`)** | Com CPU multicore e vetorização AVX, a conversão `.f32` -> `.wav` com redução de ruído roda instantaneamente, permitindo até mesmo aplicar filtros mais sofisticados ou taxas de sobreamostragem maiores. |

---

## 5. Arquitetura e Design Técnico

### 5.1. Componentes e Arquivos Modificados
- `src/miniola_cv.cpp`: Método `process_frame` extrai a fenda de áudio nas coordenadas `(audio_x, slit_y - h/2, audio_w, h)` e retorna array 1D no campo `audio_chunk`.
- `miniola.py`: Funções `abrir_sessao_audio_optico`, `fechar_sessao_audio_optico` e interceptação no `processo_escrita_disco` para despejar amostras binárias no arquivo `.f32`.
- `process.py`: Módulo de reconstrução e compilação FFmpeg/WAV.

### 5.2. Estrutura do Arquivo de Metadados de Áudio (`.json`)
```json
{
  "version": 1,
  "session_id": "20260719T153000Z",
  "started_at_utc": "20260719T153000Z",
  "closed_at_utc": "20260719T153100Z",
  "close_reason": "manual_stop",
  "mode": "variable_density",
  "fps_projecao": 24.0,
  "samples_per_frame": 780,
  "source_sample_rate": 18720,
  "frames_with_audio": 1200,
  "total_samples": 936000,
  "raw_path": "miniola_audio_20260719T153000Z.f32"
}
```

---

## 6. Critérios de Aceitação e Plano de Verificação

### 6.1. Verificação Automatizada (`tests/`)
- [x] O framework de testes `tests/` verifica se um frame simulado com variação senoidal na fenda de áudio gera um `audio_chunk` flutuante com a frequência esperada.
- [x] O linter de specs (`check_specs.py`) aprova a estrutura da SPEC-003.

### 6.2. Verificação em Hardware / Operação
- [x] Ao iniciar e parar uma gravação no painel do scanner, os arquivos `miniola_audio_{sid}.f32` e `miniola_audio_{sid}.json` são criados em `capturas/` com tamanho proporcional ao tempo e ao pitch médio.
- [x] Executar `python3 process.py --extract-audio` gera com sucesso um arquivo de áudio limpo em `output/`.

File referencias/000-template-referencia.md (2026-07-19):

# REF-XXX: [Título Oficial da Norma / Manual / Boas Práticas]

| Metadado | Valor |
| :--- | :--- |
| **Código/Instituição** | Ex.: FIAF Technical Commission / SMPTE ST 139 / Manual Ximea |
| **Ano / Edição** | Ex.: 2019 (2ª Edição) |
| **Documento Original** | Ex.: `pdfs_originais/FIAF_Digital_Preservation_v2.pdf` (ou Link Oficial) |
| **Destilado por** | Nome do Colaborador ou Agente IA |
| **Data de Resumo** | AAAA-MM-DD |

---

## 1. Escopo e Relevância para o Miniola
*(Explique brevemente por que este documento é importante para o scanner. Ex.: "Este documento define os parâmetros recomendados de resolução espacial, profundidade de cor e tolerância a engasgos mecânicos na digitalização de películas de 35mm para preservação em arquivos públicos...")*

---

## 2. Parâmetros Críticos e Tabelas de Referência
*(Extraia e formate as tabelas, números e diretrizes que impactam o código, os sensores ou a visão computacional)*

| Parâmetro / Norma | Recomendação da Instituição | Aplicação Prática no Miniola |
| :--- | :--- | :--- |
| **Resolução de Captura (35mm)** | Mínimo de 2K (2048px largura) para inspeção/acesso; 4K para masterização | O sensor Ximea em corte (`RES_W=1420, RES_H=880`) atende à faixa de inspeção em tempo real. |
| **Espaço de Cor / Bit Depth** | 10-bit ou 12-bit RAW em espaço nativo do sensor para preservação | Captura RAW8/RAW12 decodificada sem interpolação destrutiva (`subsampling=0`). |
| **Estabilidade de Pitch** | Variação de registro vertical inferior a ±0.5 linha de varredura | O cálculo instantâneo em `miniola_cv.cpp` compensa variações dinâmicas de encolhimento. |

---

## 3. Diretrizes Algorítmicas e Fórmulas
*(Se a norma contiver fórmulas matemáticas ou lógicas de inspeção de danos, documente-as aqui)*

```text
Fórmula de Encolhimento (%):
Encolhimento (%) = ((Pitch_Nominal_mm - Pitch_Medido_mm) / Pitch_Nominal_mm) * 100
```

---

## 4. Práticas de Conservação e Manuseio (Reflexo no Hardware)
- `[PRATICA-01]`: A tração mecânica sobre as perfurações de filmes de nitrato ou acetato empenado deve ser minimizada. O Miniola não utiliza pinos de registro mecânicos furos-a-dentado, confiando no registro **óptico/computacional via OpenCV**.
- `[PRATICA-02]`: A iluminação (LED na mesa de luz) deve ser fria e de espectro uniforme, evitando aquecimento termal da película na fenda de captura.

---

## 5. Especificações de SDD Vinculadas (`specs/`)
Listagem das nossas especificações técnicas que implementam ou obedecem a esta referência:
- `[SPEC-001](../specs/001-vision-engine-cpp.md)` - Compensação de encolhimento e binarização.
- `[SPEC-003](../specs/003-optical-audio-extraction.md)` - Extração de áudio óptico em conformidade com tolerâncias de densidade/área.

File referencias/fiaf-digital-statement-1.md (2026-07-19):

# REF-002: FIAF Digital Statement Parte I - Práticas de Digitalização e Sensores

| Metadado | Valor |
| :--- | :--- |
| **Código/Instituição** | FIAF Technical Commission (Digital Statement Part I) |
| **Documento Original** | `pdfs_originais/The Digital Statement FIAF` |
| **Destilado por** | Equipe Miniola / Antigravity |
| **Data de Resumo** | 2026-07-19 |

---

## 1. Escopo e Relevância para o Miniola
A Parte I do *Digital Statement* da FIAF define as recomendações éticas e técnicas para a digitalização, restauração e acesso a coleções cinematográficas, em referência aos artigos 1.4, 1.5 e 1.7 do Código de Ética da FIAF. O objetivo central é que a reprodução digital seja o mais "sem perdas" possível, mantendo as propriedades fotográficas originais da película sem introduzir distorções mecânicas ou interpolações.

Para o **Miniola**, este documento orienta a escolha e justificação da arquitetura de sensores (câmera **Ximea USB 3.0** e **Picamera2**), evidenciando os compromissos entre velocidade, custo e fidelidade na reconstrução de cores (filtro mosaico Bayer vs. sensores monocromáticos com iluminação sequencial).

---

## 2. Parâmetros Críticos e Categorização de Sensores

A FIAF classifica as arquiteturas de captura dos scanners comerciais e protótipos de arquivo em três categorias principais:

| Tipo de Sensor | Funcionamento e Transporte | Vantagens | Desvantagens / Compromissos | Relação com o Miniola |
| :--- | :--- | :--- | :--- | :--- |
| **1. Area-based Sensors (Sensores de Quadro Completo Monocromáticos)** | Capturam a área total do fotograma parado (transporte intermitente, estilo *step printing*). O sensor é nativamente "cego para cores" e realiza 3 exposições sequenciais em R, G e B (ou flashes múltiplos HDR). | Fidelidade de cor perfeita, resolução espacial total real em R, G e B, alinhamento geométrico ideal e alto alcance dinâmico sem interpolação. | Transporte intermitente mais lento; custo de hardware muito mais elevado. | Representa o padrão ouro de preservação master. A Miniola pode no futuro buscar uma implementação com transporte por motores e uma camera monocromática. |
| **2. Line Sensors (Sensores de Linha / Varredura Contínua)** | Capturam linhas horizontais individuais enquanto o filme se move continuamente, remontando a imagem 2D por software (*continuous printing*). | Alta velocidade (tempo real ou superior); elimina o tempo de parada mecânica por quadro. | Sensível a vibrações, emendas grossas (*splice bumps*) e variações na tração mecânica, que causam ondulações horizontais na imagem se o encoder não for perfeito. | A tração contínua da Miniola exige sincronia precisa via encoder e fase PLL no OpenCV para evitar deformações verticais/horizontais na linha. |
| **3. Area Color Chips (Sensores de Cor com Filtro Bayer / Mosaico)** | Captura simultânea das cores R, G e B em um único disparo usando um mosaico de microfiltros de cor (Padrão Bayer: 50% G, 25% R, 25% B). | Captura muito rápida, excelente custo-benefício e mecânica simplificada (um único disparo por fotograma). | Subamostragem espacial de cor: um sensor 2K/4K Bayer captura apenas metade da resolução em verde e um quarto em vermelho e azul. A imagem final requer algoritmos de interpolação (*demosaicing/debayering*). | É o modo padrão das nossas câmeras `ximea` (módulo colorido) e `pi` (CSI). Por isso, salvamos o RAW ou efetuamos o debayering com máxima qualidade de interpolação. |

---

## 3. Diretrizes de Supressão de Riscos e Avarias
A FIAF recomenda técnicas físicas/ópticas para suprimir riscos superficiais da base do filme durante a digitalização, evitando que se tornem parte da informação da imagem, o que é superior à remoção por software post-facto:

1. **Wet Gates (Janela Úmida ou Aquário)**:
   - Preenchimento dos riscos da película com um líquido de índice de refração compatível ao do suporte fotográfico, eliminando o espalhamento de luz (*light scattering*) que torna os riscos visíveis.
   - Eficaz também contra manchas de mofo e decomposição. Requer espaçamento mecânico rigoroso na fenda para não degradar a nitidez da lente.
   - Será difícil conseguir um sistema de *wet gate* para a miniola, apenas a longo prazo e com desenvolvimento avançado.
2. **Luz Difusa (*Diffuse Illumination*)**:
   - Uso de fontes de luz não-especulares (espalhadas e difusas). Reduz drasticamente a visibilidade de riscos superficiais na base sem a complexidade e os riscos químicos dos líquidos de *wet gate*.
   - **Na Miniola**: Adotamos painéis de iluminação LED difusos de alto CRI na mesa/fenda ótica para minimizar o espalhamento de luz em riscos sem molhar a película (`[PRATICA-02]`).
3. **Mapeamento Infravermelho (*IR / Dirt-map Scanning*)**:
   - Para películas coloridas integrais cromogênicos com corantes transparentes ao IR (Eastmancolor/Fujicolor), um canal infravermelho extra detecta poeira e riscos superficiais para gerar uma máscara de erro (*dirt map*), permitindo que softwares de restauro isolem a intervenção às avarias.

---

## 4. Granulação Fotográfica vs. Ruído de Captura
- A película analógica possui dois tipos de "informação": o detalhe visual da cena e a textura dos grãos fotográficos de haleto de prata ou nuvens de corante.
- O escaneamento converte essa distribuição aleatória tridimensional em uma grade estática de pixels 2D. 
- A Miniola deve evitar compressão destrutiva temporal no momento da captura para preservar a textura aleatória autêntica do grão (*graininess*), em vez de borrá-lo ou transformá-lo em artefatos de compressão de bloco.

---

## 5. Especificações de SDD Vinculadas (`specs/`)
- `[SPEC-002](../specs/002-camera-abstraction.md)` - Abstração de câmeras (`ximea`, `pi`, `uvc`) e processamento de formatos RAW/Bayer em conformidade com as diretrizes da FIAF para sensores *Area Color Chips*.
- `[SPEC-004](../specs/004-multiprocessing-capture-pipeline.md)` - Loop de captura assíncrona que preserva os buffers de imagem originais sem compressão intermediária com perda.

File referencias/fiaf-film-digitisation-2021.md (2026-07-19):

# REF-004: FIAF Film Digitisation - Diretrizes e Melhores Práticas (2021)

| Metadado | Valor |
| :--- | :--- |
| **Código/Instituição** | FIAF Technical Commission (Film Digitisation Best Practices 2021) |
| **Documento Original** | `pdfs_originais/Film_Digitisation_2021.pdf` |
| **Destilado por** | Equipe Miniola / Antigravity |
| **Data de Resumo** | 2026-07-19 |

---

## 1. Escopo e Relevância para o Miniola
O documento *Film Digitisation* (2021) consolida as melhores práticas práticas da FIAF na montagem de laboratórios de digitalização arquivística. Ele abrange a escolha do elemento fílmico, controle de temperatura/umidade, inspeção física pré-varredura, mecânica de transporte, iluminação e o equilíbrio entre qualidade bruta e velocidade de captura.

Para o **Miniola**, este documento valida nossas decisões de engenharia de baixo custo focada em preservação: a tração sem pinos dentados (*sprocketless continuous capstan*), a iluminação LED difusa fria, a captura de toda a largura do suporte (*overscan* com perfurações) e a geração de metadados sidecar/DPX auditáveis.

---

## 2. Parâmetros Críticos e Tabelas de Referência

| Área / Parâmetro | Recomendação da FIAF (2021) | Aplicação e Alinhamento no Miniola |
| :--- | :--- | :--- |
| **1. Transporte Mecânico (*Film Transport*)** | Transporte suave com tensão controlada (*gentle tension control*) ou tracionamento contínuo sem pinos (*sprocketless/pinless*). É mandatório para filmes danificados, abaulados, com emendas antigas ou encolhimento superior a 1.0%. | O Miniola adota tração contínua macia e sincronização por **Visão Computacional em C++ (`miniola_cv.cpp`)**, eliminando qualquer engrenagem dentada que possa rasgar perfurações fragilizadas. **É importante ressaltar que o estado atual da Miniola usa um sistema de transporte manual da película com total controle do operador sobre a tensão, porém temos o plano de implementar uso de motores passo no futuro e criar um híbrido transporte manual/motoriazado*. Para filmes em bom estado poderemos usar o sistema motorizado, em caso de filmes muito deteriorados seá utilizado o transporte manual (por manivela em uma mesa de revisão). |
| **2. Fonte de Luz (*Illumination System*)** | Fonte de luz difusa e fria (LED de espectro contínuo com alto CRI/TLCI), regulada termicamente para evitar sobreaquecimento da película no gate. | Utilização de matriz LED difusa acionada na mesa, sem emissão térmica perigosa na faixa infravermelha ou ultravioleta (`[PRATICA-02]`). |
| **3. Inspeção e Preparação Pré-Scan** | Toda película deve passar por inspeção física prévia na mesa de revisão (*winding table*) para reparo de emendas quebradas, limpeza ultrassônica/manual de poeira e anotação de encolhimento e danos mecânicos. | Criamos o **Anotador Visual de Ground Truth (`tools/templates/anotador.html`)** para permitir que o arquivista documente exatamente o encolhimento, bitola e avarias da amostra antes ou durante a captura. |
| **4. Varredura Total (*Overscan to Edges*)** | Captura completa das bordas (*full aperture / edge-to-edge*) para registrar códigos de borda (*edge numbers*), carimbos de censura, marcas de emenda, marcas de som e a geometria da perfuração. | O crop da ROI de visão (`roiBox`) no nosso software é intencionalmente dimensionado para abranger as perfurações e bordas, preservando a integridade histórica do artefato fílmico. |
| **5. Metadados e Rastreabilidade** | Documentação técnica rigorosa associada a cada arquivo capturado (dados do scanner, lente, velocidade em FPS, sensor, data e operador). | O Miniola exporta arquivos sidecar `.json` e embutirá metadados nos cabeçalhos DPX em conformidade com as normas FADGI/SMPTE (`REF-005`). |

---

## 3. Diretrizes de Manuseio e Segurança do Suporte
- **Películas de Nitrato e Acetato Degradado (*Vinegar Syndrome*)**: Exigem tração mecânica com o mínimo de atrito no *gate*. Se a película apresentar ondulações severas (*buckling/fluting*), guias laterais com molas suaves devem manter o foco da lente sem esmagar o filme.
- **Velocidade de Varredura**: Embora scanners lineares modernos operem em altas velocidades (`24 FPS` a `120 FPS+`), a velocidade de digitalização deve ser reduzida imediatamente se a película apresentar fragilidade extrema, rasgos repetidos nas perfurações ou emendas soltas.

---

## 4. Especificações de SDD Vinculadas (`specs/`)
- `[SPEC-001](../specs/001-vision-engine-cpp.md)` - Rastreamento por fase circular tolerante a emendas e perfurações rasgadas.
- `[SPEC-004](../specs/004-multiprocessing-capture-pipeline.md)` - Desacoplamento da fila de gravação para garantir que o loop de tração mecânica não sofra solavancos por bloqueios de I/O em disco.

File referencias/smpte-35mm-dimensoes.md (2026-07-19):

# REF-001: Padrões e Dimensões Geométricas da Bitola 35mm (SMPTE / ANSI)

| Metadado | Valor |
| :--- | :--- |
| **Código/Instituição** | SMPTE ST 139 (35mm Film - Perforated KS) & SMPTE ST 93 (BH) |
| **Documento Original** | Padrões Internacionais SMPTE / ISO Cinematografia |
| **Destilado por** | Equipe Miniola / Antigravity |
| **Data de Resumo** | 2026-07-19 |

---

## 1. Escopo e Relevância para o Miniola
O algoritmo de visão computacional em C++ (`miniola_cv.cpp`) detecta as perfurações na película 35mm em movimento para disparar o gatilho eletrônico (`capturar = true`) e medir o encolhimento do filme em tempo real. 

Conhecer as dimensões nominais padronizadas pela SMPTE/ANSI para as variações de perfuração (Kodak Standard - KS, Bell & Howell - BH e CinemaScope - CS) permite que o filtro geométrico de contornos do OpenCV (`0.2 < w/h < 2.5` e área em `200 < area < 10000`) isole perfeitamente um furo verdadeiro e ignore poeira, emendas de fita ou rasgos na borda da película.

---

## 2. Parâmetros Críticos e Tabelas de Referência

| Tipo de Perfuração | Largura (W) | Altura (H) | Proporção (W/H) | Aplicação Principal / História |
| :--- | :--- | :--- | :--- | :--- |
| **KS (Kodak Standard / Posi)** | 2.79 mm (`0.110"`) | 1.98 mm (`0.078"`) | **1.41** | Padrão mundial em cópias de exibição (positivos) de 35mm desde a década de 1920 até o fim do filme fotográfico. Cantos arredondados. |
| **BH (Bell & Howell / Neg)** | 2.79 mm (`0.110"`) | 1.85 mm (`0.073"`) | **1.51** | Usado principalmente em negativos de câmera e masters de laboratório pela alta precisão de pinos mecânicos. Cantos planos/ovais. |
| **CS (CinemaScope / Fox)** | 1.98 mm (`0.078"`) | 1.85 mm (`0.073"`) | **1.07** | Perfurações estreitas ("Fox holes") criadas nos anos 1950 para acomodar 4 pistas magnéticas de som surround ao lado da imagem anamórfica. |

### 2.1. Pitch Nominal (Distância Centro a Centro entre Furos)
O pitch é a distância percorrida na vertical entre o centro de uma perfuração e o centro da perfuração seguinte:

| Norma / Tipo de Estoque | Pitch Nominal em Milímetros | Pitch Nominal em Polegadas |
| :--- | :--- | :--- |
| **KS Long Pitch (Positivo Padrão)** | **4.750 mm** | `0.1870"` |
| **BH Short Pitch (Negativo Padrão)** | **4.740 mm** | `0.1866"` |
| **Filmes Antigos / Nitrato (Encolhidos)** | **4.600 mm a 4.700 mm** | Encolhimento de 1.0% a 3.0% |

---

## 3. Diretrizes Algorítmicas no Motor OpenCV (`miniola_cv.cpp`)
1. **Passo Padrão no Fotograma 35mm**: Exatamente **4 perfurações por fotograma de imagem** em formato Standard/Academy (razão pela qual `contador_perfs_ciclo >= 4` aciona a captura). Em formatos Techniscope (Super35 2-perf), o passo é de 2 perfurações.
2. **Razão de Aspecto (`w/h`) no Sensor**:
   - Para um furo KS (proporção nominal 1.41), se a câmera estiver perpendicular ao filme, a caixa delimitadora (`boundingRect`) em pixels terá largura superior à altura.
   - O filtro do nosso código aceita `0.2 < w/h < 2.5` para acomodar inclinações ou perfurações rasgadas/avariadas sem rejeitar o quadro.
3. **Calibração Dinâmica de Pitch (`pitch_padrao_px`)**:
   - Se 4.75 mm de película equivalem a `195.0 pixels` no sensor (com a lente em foco nominal `foco_atual = 14.5`), então **1 milímetro na película corresponde a exatamente 41.05 pixels**.
   - Qualquer desvio em que a média dos últimos pitches detectados seja inferior ao pitch nominal (`PITCH_PADRAO_PX`) reflete o encolhimento físico da película em tempo real:

```text
Fórmula de Encolhimento (%):
Encolhimento (%) = ((Pitch_Nominal_mm - Pitch_Medido_mm) / Pitch_Nominal_mm) * 100
Ou no espaço do sensor (pixels):
Encolhimento (%) = (1.0 - (pitch_medio / PITCH_PADRAO_PX)) * 100.0
```

---

## 4. Práticas de Conservação e Manuseio (Reflexo no Hardware)
- `[PRATICA-01]`: Películas com mais de 1.5% de encolhimento não podem ser projetadas ou digitalizadas em equipamentos com pinos mecânicos dentados (*sprockets*), pois rasgarão as perfurações. O Miniola elimina os pinos dentados através do tração contínua macia por cabrestante (*capstan*) e registro computacional via OpenCV.
- `[PRATICA-02]`: A iluminação na fenda deve ser fria (LED Diffuse Light), evitando dilatação térmica e expansão do pitch durante a inspeção.

---

## 5. Especificações de SDD Vinculadas (`specs/`)
- `[SPEC-001](../specs/001-vision-engine-cpp.md)` - Binarização, contornos de perfurações e cálculo do pitch e encolhimento.
- `[SPEC-007](../specs/007-ground-truth-annotator.md)` - Anotador visual para marcação manual das 4 perfurações e cálculo de pitch em pixels.

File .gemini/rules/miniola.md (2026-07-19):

# Regras para o Assistente Gemini / Antigravity - Projeto Miniola

Ao atuar neste repositório (`miniola`), você DEVE seguir estritamente as diretrizes abaixo e consultar o arquivo principal `AGENTS.md` para referência completa.

## 1. Spec-Driven Development (SDD) Obrigatório
- **Consultar Normas e Referências (`referencias/`)**: Antes de desenhar algoritmos de visão ou propor novas especificações, consulte sempre os documentos em `referencias/` (padrões FIAF, SMPTE, manuais de sensores) para garantir alinhamento com as melhores práticas de preservação audiovisual.
- **Nunca implementar ou alterar funcionalidades no código C++/Python** sem antes verificar se existe uma especificação na pasta `specs/`.
- Se a funcionalidade for nova ou representar uma mudança estrutural/arquitetural, **crie ou edite primeiro o arquivo `specs/XXX-nome.md`** usando o template `specs/000-template.md`.
- Siga sempre o ciclo: Consulte (`referencias/`) -> Especifique (`specs/`) -> Revise Impacto Multi-Plataforma -> Implemente -> Valide (`check_specs.py` e `tests/`).

## 2. Arquitetura Multi-Plataforma (Raspberry Pi vs. MiniPCs x86_64)
- O Miniola roda tanto em Raspberry Pi 5 (`arm64`) quanto em MiniPCs / Mac Mini Late 2012 (`x86_64` Linux).
- Evite hardcoding exclusivo de Raspberry Pi (`pykms`, `/sys/class/thermal/`, caminhos `/home/felipe/miniola/capturas`). Use abstrações de plataforma ou detecção `platform.machine()`.
- Respeite o contrato modular em `cameras/` (`ximea`, `pi`, `uvc`, `mock`).

## 3. Restrições de Hardware e Performance
- Mantenha todo o processamento pesado de visão computacional de alto FPS (binarização, contornos de perfuração, pitch e gatilho) em **C++** via `pybind11` (`src/miniola_cv.cpp`).
- Nunca bloqueie o loop de captura de imagem com gravações em disco ou chamadas de codificação de vídeo (`ffmpeg`); utilize sempre a fila assíncrona `multiprocessing.Queue`.

## 4. Testes e Validação
Sempre verifique seu trabalho executando:
```bash
python3 scripts/check_specs.py
python3 -m unittest discover -s tests
```

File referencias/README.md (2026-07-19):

# Referências Normativas e Arquivísticas (`referencias/`)

Esta pasta armazena o **conhecimento arquivístico, normas técnicas, manuais de hardware e diretrizes de preservação** que servem como fundamentação (*Ground Truth Documental*) para o **Spec-Driven Development (SDD)** do Miniola.

---

## Por que converter PDFs para Markdown (`.md`)?

Para garantir a máxima eficiência na colaboração entre desenvolvedores humanos e **Agentes de IA (Gemini/Antigravity)**, adotamos a prática de **destilar e converter documentos em PDF (como diretrizes da FIAF e manuais) para arquivos Markdown (`.md`) estruturados**:

1. **Leitura Instantânea por Agentes**: Arquivos `.md` são lidos nativamente e com altíssima velocidade por ferramentas de busca semântica (`grep_search`) e IDEs agentizadas, sem gastar tokens excessivos com diagramação de páginas ou ruído de leitura de PDF.
2. **Citação Exata nas Especificações (`specs/`)**: Cada especificação técnica em `specs/` pode citar linhas exatas ou seções de normas em `referencias/` (ex.: `[referencias/fiaf-preservacao-digital.md#L45-L60](file:///home/felipe/Projetos/miniola/referencias/fiaf-preservacao-digital.md#L45-L60)`).
3. **Padrão e Limpeza**: Tabelas de tolerância geométrica, fórmulas matemáticas de pitch e parâmetros de digitalização são mantidos limpos e prontos para verificação em código.

> **Dica**: Se desejar manter o PDF original baixado da FIAF ou do fabricante, guarde-o na subpasta `referencias/pdfs_originais/`, e crie o arquivo `.md` correspondente na raiz de `referencias/` usando o nosso template `000-template-referencia.md`.

---

## Índice de Referências Ativas

| ID | Documento / Norma | Tema Principal | Arquivo MD |
| :--- | :--- | :--- | :--- |
| **REF-000** | Template de Referência Normativa | Estrutura padrão para converter normas/manuais em MD | `000-template-referencia.md` |
| **REF-001** | Padrões e Dimensões da Bitola 35mm (SMPTE/ANSI) | Geometria de perfurações BH, KS e CS, pitch nominal e tolerâncias | `smpte-35mm-dimensoes.md` |
| **REF-002** | FIAF Digital Statement I - Práticas de Digitalização | Sensores de área, linha e Bayer/mosaico; supressão de riscos por Wet Gate/difusão | `fiaf-digital-statement-1.md` |
| **REF-003** | FIAF Digital Statement II - Digitalização e Preservação | Overscan, resolução (2K/4K/6K+), densidade Cineon 10-bit log e aliasing | `fiaf-digital-statement-2.md` |
| **REF-004** | FIAF Film Digitisation - Diretrizes e Práticas (2021) | Transporte mecânico suave sem pinos, iluminação fria e inspeção pré-scan | `fiaf-film-digitisation-2021.md` |
| **REF-005** | FADGI DPX Embedded Metadata (`SMPTE ST 268`) | Metadados obrigatórios no cabeçalho binário/ASCII de arquivos DPX | `fadgi-dpx-embedded-metadata.md` |
| **REF-006** | FADGI Digitizing Motion Picture Film (SOW) | Fluxogramas de captação para som óptico, magnético e filmes silenciosos | `fadgi-digitizing-motion-picture-film.md` |
| **REF-007** | FADGI Audio ADC Performance Specifications | Métricas de ensaio e tolerâncias (High Level & Low Cost) para conversores de áudio | `fadgi-audio-adc-performance.md` |
| **REF-008** | Kodak Essential Reference Guide for Filmmakers | Bases de acetato/ESTAR, cristais T-Grain, curvas sensitométricas H&D e códigos | `kodak-filmmakers-reference-guide.md` |

---

## Como Adicionar uma Nova Referência

1. Copie o arquivo `000-template-referencia.md` para o nome do documento (ex.: `fiaf-audio-preservation.md`).
2. Extraia os pontos essenciais, tabelas e parâmetros de preservação do PDF ou documento original.
3. Registre o novo documento no índice acima e vincule-o às especificações de `specs/` relevantes.

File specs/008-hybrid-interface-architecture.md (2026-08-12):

# SPEC-008: Arquitetura Híbrida de Interfaces (Web Dashboard & App Nativo Desktop)

| Metadado | Valor |
| :--- | :--- |
| **ID da Especificação** | `SPEC-008` |
| **Status** | `Draft` |
| **Autor** | Equipe Miniola |
| **Data de Criação** | 2026-07-19 |
| **Última Atualização** | 2026-07-19 |

---

## 1. Contexto e Objetivo
O **Miniola** opera em ambientes e hardwares heterogêneos de preservação audiovisual, dividindo-se em dois cenários principais no laboratório:

1. **Modo Headless (Embarcado em Raspberry Pi 5/4):** O hardware de digitalização fica acoplado à mesa enroladeira sem monitor conectado. Rodar um ambiente desktop (Wayland/X11) no Raspberry Pi consome entre 600 MB e 900 MB de RAM e compete pelos ciclos de CPU/GPU com o motor crítico C++ (`miniola_cv`) e a fila assíncrona de gravação no RAM drive (`tmpfs` de 1 GB da `SPEC-004`). Portanto, no RPi, o sistema operacional deve rodar sem ambiente gráfico (*Debian Headless / RPi OS Lite*), sendo controlado remotamente via rede.
2. **Modo Workstation de Bancada (Mac Mini ou MiniPCs `x86_64` com Monitor Dedicado):** O computador de digitalização fica sobre a bancada com um monitor de alta resolução conectado localmente. Nesse cenário, o arquivista necessita de **latência visual zero** para ajuste físico fino da rosca da lente (foco óptico sub-pixel) e alinhamento mecânico da película, além de inspeção dos pixels brutos capturados sem perda de nitidez ou artefatos de compressão de rede (JPEG/MJPEG/WebRTC).

Para atender com máxima excelência a ambos os cenários sem duplicar lógica de negócio ou comprometer a performance do processamento a 120+ FPS, esta especificação estabelece a **Arquitetura Híbrida de Interfaces do Miniola**: um núcleo backend desacoplado (`miniola-core`) capaz de alimentar tanto um **Web Dashboard otimizado** (para operação remota e headless) quanto um **App Nativo Desktop em PySide6/Qt** (para estações de bancada ou clientes remotos de alta performance).

---

## 2. Requisitos Funcionais

- `[RF-01] Desacoplamento do Core (Serviço Agnóstico)`: O loop principal do Miniola (`miniola.py` refatorado) deve separar estritamente a lógica de captura e controle da camada de apresentação, expondo chamadas unificadas de transporte (`REC`, `PAUSE`), calibração (`set_crop`, `offset`), e telemetria (temperatura, FPS, pitch instantâneo) através de uma API REST/WebSocket ou memória compartilhada.
- `[RF-02] Modo Headless & Web Dashboard Renovado (SPEC-005)`: Para uso em sistemas sem ambiente gráfico (como o Raspberry Pi Headless), o Miniola deve continuar servindo o Web Dashboard no navegador, recebendo as seguintes evoluções de UI/UX profissional:
  - **CSS Grid Responsivo & Paleta Dark Pro (`#181818`)**: Substituição da geração de mosaicos estáticos (`np.vstack`/`np.hstack`) por layout web limpo com guias vetoriais de enquadramento (4-perf, 3-perf, 16mm).
  - **Scopes de Engenharia**: Exibição clara do Histograma de Luminância (0-255 IRE), Waveform monitor e barra cinza da Fenda de Áudio Óptico (`AUDIO_READ_W`) com medidor VU de pico.
  - **Zebra de Exposição Comutável**: Alerta visual de superexposição (clipping > 245) com proporção de aspecto real preservada, operando como camada (toggle) sobre o vídeo principal sem esticar ou distorcer a prévia.
- `[RF-03] App Nativo Desktop Multiplataforma (PySide6 / Qt6)`: O sistema deve disponibilizar uma aplicação desktop nativa para Linux, macOS e Windows operando em dois modos de conexão:
  - **Modo Local (Memória RAM Direta / Latência Zero)**: Quando executado na mesma máquina que o scanner (Workstation x86_64), o app acessa diretamente os arrays NumPy dos buffers da câmera (`ultimo_frame_bruto` e `ultimo_frame_binario`) na memória, renderizando via GPU (`QImage`/OpenGL) a 60 FPS cravados sem passar por compressão ou codificação JPEG.
  - **Modo Remoto (Cliente LAN)**: Quando executado no computador pessoal ou notebook do arquivista apontando para o IP de um Miniola Headless (RPi), o app atua como cliente de rede, consumindo a API e renderizando os gráficos de telemetria (curva de pitch em tempo real e osciloscópio) nativamente com aceleração gráfica local.
- `[RF-04] Alinhamento Óptico Sub-Pixel (Foco na Bancada)`: No modo local, o App Nativo deve permitir zoom digital instâneo na ROI das perfurações e na fenda de áudio para conferência milimétrica do foco da lente e nitidez dos furos antes do início da sessão de captura.
- `[RF-05] Metrologia de Vídeo Avançada (Futuro)`: Implementação de Scopes de Vídeo em tempo real (Waveform Monitor para Luminância e Vectorscope para Crominância). Esses gráficos devem ser gerados de forma assíncrona sobre o preview em baixa resolução para não impactar a thread de captura e permitir calibragem fina (color grading) do telecine.

---

## 3. Requisitos Não-Funcionais e Performance

- `[RNF-01] Pegada de Memória no Modo Headless (RPi)`: Em Raspberry Pi 5/4 rodando Debian Headless sem X11/Wayland, o consumo total de memória do serviço base do Miniola + motor C++ (`miniola_cv`) não deve ultrapassar 350 MB de RAM, garantindo a disponibilidade e estabilidade do RAM Drive `tmpfs` de 1 GB (`SPEC-004`).
- `[RNF-02] Latência Visual e Renderização Local`: No App Nativo em Modo Local, o tempo decorrido entre a disponibilização de um quadro binarizado/bruto pelo C++ e a sua renderização na tela do monitor não deve exceder 16 milissegundos (60 Hz fluidos), com zero artefatos de compressão.
- `[RNF-03] Intocabilidade da Vazão C++`: Nem o streaming web MJPEG nem a renderização do App Nativo em PySide6 podem bloquear ou atrasar a thread de captura do motor `miniola_cv.cpp`, preservando o processamento em tempo real de 120 FPS a 180 FPS.

---

## 4. Matriz de Impacto Multi-Plataforma

| Plataforma | Comportamento Esperado / Restrições Específicas |
| :--- | :--- |
| **Raspberry Pi 5/4 (`arm64`)** | Operação recomendada em **Modo Headless (Sem Ambiente Gráfico X11/Wayland)** para economizar RAM e recursos da CPU ARM. O controle e monitoramento são realizados via **Web Dashboard Renovado** no navegador ou conectando o **App Nativo Remoto** a partir de um PC de controle na rede local. |
| **Mac Mini / MiniPCs (`x86_64`)** | Operação ideal como **Workstation de Bancada com Monitor Dedicado**. Execução local do **App Nativo Desktop (`PySide6`)** com latência zero via acesso direto à memória dos frames, aproveitando aceleração de GPU e otimizações nativas x86_64 sem overhead de codificação de stream de rede. |

---

## 5. Arquitetura e Design Técnico

### 5.1. Divisão em Camadas (Desacoplamento)
Para permitir a convivência harmoniosa das duas interfaces, a estrutura evoluirá para:

```
[ Provedores de Câmera (`cameras/`) ] ---> [ Motor C++ (`src/miniola_cv.cpp`) ]
                                                    |
                                                    v
                                      [ Core Desacoplado (`miniola.py`) ]
                                         /                          \
                        (Filas e Memória Direta)         (API REST / WebSockets / MJPEG)
                                       /                              \
                                       v                               v
                     [ App Nativo Desktop (`PySide6`) ]      [ Web Dashboard (`index.html`) ]
                     - Workstation Local (Latência Zero)     - RPi Headless / Acesso Browser
                     - Cliente Remoto em LAN                 - CSS Grid & Scopes Profissionais
```

### 5.2. Módulos e Componentes Alvo
- `web/` (`routes.py` e gerador de stream): Extração das rotas `@app.route` do `miniola.py` (Item 2.1 do `TODO_PROXIMA_SESSAO.md`), mantendo compatibilidade com a `SPEC-005`.
- `workers/recorder.py`: Isolamento do processo de gravação assíncrona (`processo_escrita_disco`).
- `gui/` (Futuro módulo de desktop nativo): Pacote PySide6/Qt6 contendo componentes visuais (`scopes.py`, `live_view.py`, `transport_bar.py`) conectáveis ao core.

---

## 6. Critérios de Aceitação e Plano de Verificação

### 6.1. Verificação Automatizada (`tests/` & `check_specs.py`)
- [ ] A checagem `python3 scripts/check_specs.py` não deve apontar erros, validando que a `SPEC-008` cumpre todas as regras do SDD e da Matriz Multi-Plataforma.
- [ ] Os testes unitários em `tests/` devem confirmar que o isolamento do core não quebra as rotas e contratos da `SPEC-005`.

### 6.2. Verificação Operacional / Bancada
- [ ] No Raspberry Pi em modo Headless, verificar com `htop` / `free -m` que o consumo de memória RAM permanece abaixo de 350 MB sem interface gráfica rodando no sistema operacional.
- [ ] No Mac Mini / PC de bancada com monitor, validar que o preview visual da câmera exibe os quadros sem compressão e com resposta instantânea ao ajuste de foco mecânico da lente.

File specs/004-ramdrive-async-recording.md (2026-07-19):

# SPEC-004: Pipeline de Gravação Assíncrona e RAM Drive (tmpfs)

| Metadado | Valor |
| :--- | :--- |
| **ID da Especificação** | `SPEC-004` |
| **Status** | `Completed` |
| **Autor** | Equipe Miniola |
| **Data de Criação** | 2026-07-19 |
| **Última Atualização** | 2026-07-19 |

---

## 1. Contexto e Objetivo
Capturar imagens de 1420x880 em 120 FPS no loop do sensor gera centenas de megabytes de dados brutos por segundo. Se o thread ou processo que lê o sensor tentar salvar cada quadro diretamente em disco ou fazer conversão de cor (Debayer) sincronicamente, haverá perda de quadros (`frame drop`) e engasgo no buffer USB. Além disso, em cartões MicroSD no Raspberry Pi, a escrita contínua em alta velocidade degrada a mídia e é excessivamente lenta.

Esta especificação define a arquitetura de gravação assíncrona em núcleo isolado (`multiprocessing.Process`) acoplada ao uso de armazenamento de latência ultra-baixa (`tmpfs` em RAM ou SSD NVMe).

## 2. Requisitos Funcionais
- `[RF-01]`: O sistema deve manter uma fila de comunicação multi-processo `fila_gravacao = mp.Queue(maxsize=30)` entre o loop de captura (`miniola.py`) e o processo de gravação em disco (`processo_escrita_disco`).
- `[RF-02]`: Quando o gatilho da perfuração disparar e `GRAVANDO == True`, o frame inteiro de overscan (`img_bgr`) e os metadados matemáticos de registro (`cx`, `cy`, `ox`, `oy`, `cw`, `ch`, `pitch_inst`) devem ser inseridos em `fila_gravacao` sem bloquear o loop de visão (`block=False`).
- `[RF-03]`: Se `fila_gravacao` estiver cheia (por saturação momentânea de I/O), o quadro excedente deve ser descartado com aviso de log (`[WARN] Fila de gravação cheia`), mas sem travar a captura da câmera.
- `[RF-04]`: O `processo_escrita_disco` deve rodar como um processo separado da CPU (desonerando o Core 0/1) e processar mensagens de gravação de imagens (`miniola_{n:06d}.jpg`), pedaços de áudio e telemetria de registro em arquivos `.jsonl` (`miniola_tracking_{session_id}.jsonl`).
- `[RF-05]`: Se a imagem for entregue em formato RAW8 Bayer de 1 canal (`len(shape) == 2`), o `processo_escrita_disco` deve executar o debayering assíncrono para BGR (`cv2.cvtColor(..., BAYER_MODE)`) e comprimir via `cv2.imwrite` com qualidade 95 (`libjpeg-turbo` C++ nativo), evitando conversões duplas para RGB ou compilações lentas via PIL.
- `[RF-06]`: A pós-compilação dos fotogramas gravados e da trilha de áudio ótico via `process.py` requer obrigatoriamente a presença do executável de sistema `ffmpeg` no `PATH` do SO host (`sudo apt-get install -y ffmpeg`).

## 3. Requisitos Não-Funcionais e Performance
- `[RNF-01]`: A gravação assíncrona deve garantir que o tempo gasto pela função `processar_captura` no loop da câmera seja inferior a 0.5 ms.
- `[RNF-02]`: A compressão JPEG via `cv2.imwrite(..., quality=95)` no processo isolado deve manter tempo de execução inferior a 5 ms por quadro, esvaziando a fila de IPC instantaneamente sem causar saturação de memória ou queda de pacotes no barramento USB 3.0 (`dropframes`).

---

## 4. Matriz de Impacto Multi-Plataforma

| Plataforma | Comportamento Esperado / Restrições Específicas |
| :--- | :--- |
| **Raspberry Pi 5/4 (`arm64`)** | Requer obrigatoriamente a montagem do diretório de captura como RAM Drive em `/etc/fstab` (`tmpfs /home/felipe/miniola/capturas tmpfs defaults,noatime,size=1024M 0 0`). Devido ao limite de 1GB de RAM, as sessões de captura ao vivo devem ser processadas e limpas (`rout` / `r`) frequentemente. |
| **Mac Mini / MiniPCs (`x86_64`)** | Com 8GB a 16GB+ de RAM ou SSDs internos NVMe/SATA de alta velocidade (500 MB/s a 3500 MB/s), o limite de 1GB de `tmpfs` pode ser expandido ou flexibilizado, permitindo digitalizar rolos de filme maiores sem esgotar o buffer temporário. |

---

## 5. Arquitetura e Design Técnico

### 5.1. Componentes e Arquivos Modificados
- `miniola.py`: Definição de `fila_gravacao = mp.Queue(maxsize=30)` e `processo_escrita_disco`.
- `process.py`: Consome os arquivos `.jpg`, `.jsonl` e `.f32` salvos no diretório de captura.

### 5.2. Fluxo de Fila Multiprocessada
```mermaid
sequenceDiagram
    participant Cam as Camera Loop (Core 0/1)
    participant Cpp as miniola_cv (C++)
    participant Queue as fila_gravacao (mp.Queue)
    participant Worker as processo_escrita_disco (Core 2/3)
    participant Disk as tmpfs / SSD (`capturas/`)

    Cam->>Cpp: process_frame(frame_raw)
    Cpp-->>Cam: ret (capturar=True, cx_a, cy_a, audio_chunk)
    Cam->>Queue: put({"type": "audio_chunk", "data": audio_chunk}, block=False)
    Cam->>Queue: put({"type": "frame", "img_bgr": frame_raw, "filename": "miniola_000001.jpg", ...}, block=False)
    Note over Cam: Loop da câmera continua imediatamente
    Worker->>Queue: get()
    Note over Worker: Converte Bayer -> BGR -> RGB e comprime JPEG em núcleo paralelo
    Worker->>Disk: imwrite / save + log JSONL tracking
```

---

## 6. Critérios de Aceitação e Plano de Verificação

### 6.1. Verificação Automatizada (`tests/`)
- [x] O script de verificação (`check_specs.py`) valida o contrato de isolamento de processos e enfileiramento.
- [x] O teste unitário simulando `processo_escrita_disco` confirma que pacotes RAW de 1 canal são convertidos com o modo Bayer selecionado antes da gravação.

### 6.2. Verificação em Hardware / Operação
- [x] Ao disparar `rec` no painel de comando e rodar o filme no scanner, os quadros `miniola_00000X.jpg` e o log `miniola_tracking_{sid}.jsonl` são gravados em `capturas/` em tempo real sem causar quedas no FPS exibido na telemetria.

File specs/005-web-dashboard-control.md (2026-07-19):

# SPEC-005: Dashboard Web e Controle Interativo (Flask)

| Metadado | Valor |
| :--- | :--- |
| **ID da Especificação** | `SPEC-005` |
| **Status** | `Completed` |
| **Autor** | Equipe Miniola |
| **Data de Criação** | 2026-07-19 |
| **Última Atualização** | 2026-07-19 |

---

## 1. Contexto e Objetivo
Para possibilitar a inspeção e calibração de películas 35mm sem a necessidade de monitores físicos conectados diretamente ao hardware (modo *headless* em Raspberry Pi ou MiniPCs em rack/bancada), o Miniola fornece um dashboard web interativo servido via Flask (`miniola.py`). 

O dashboard permite visualização ao vivo com telemetria (perfurações detectadas, linhas de gatilho, pista de áudio em escala de cinza, histograma de luminância e alerta de exposição *Zebra*), bem como o ajuste visual da geometria de corte (Crop/ROI) e monitoramento térmico/sistema via rotas REST HTTP.

## 2. Requisitos Funcionais
- `[RF-01]`: O servidor Flask deve rodar no processo principal (`app = Flask(__name__)`), desativando logs verbosos de requisição do `werkzeug` (`log.setLevel(logging.ERROR)`) para não poluir o terminal de controle.
- `[RF-02]`: A rota de streaming ao vivo (`@app.route('/video_feed')` ou equivalente consumida pelo template) deve chamar `generate_dashboard()` em generator de Multipart MJPEG (`--frame\r\nContent-Type: image/jpeg\r\n\r\n`), emitindo quadros compostos a aproximadamente 15-20 FPS (`time.sleep(0.06)`).
- `[RF-03]`: O quadro do dashboard deve compor os seguintes painéis virtuais:
  - **Live View (Superior Esquerdo)**: Imagem redimensionada da câmera com retângulos da ROI de visão, ROI de áudio (amarelo) e linha de gatilho de perfuração (`LINHA_GATILHO_Y +- MARGEM_GATILHO`).
  - **Perfurações Binárias (Painel Esquerdo)**: Exibição da imagem binarizada gerada pelo motor C++ (`ultimo_frame_binario`).
  - **Pista de Áudio (Painel Direito)**: Visualização em escala de cinza da fenda de som (`AUDIO_READ_W`), permitindo conferir o foco óptico e o alinhamento da fenda.
  - **Zebra & Histograma (Inferior)**: Visualização de superexposição (vermelho se luma > 245) e subexposição (azul se luma < 10) em uma prévia do crop final, acompanhada de histograma em tempo real de 256 níveis.
- `[RF-04]`: A rota REST `@app.route('/set_crop')` deve receber parâmetros `x, y, w, h` via query string ou JSON do navegador, calcular as coordenadas relativas ao centro do furo de ancoragem (`OFFSET_X`, `OFFSET_Y_CROP`) e impor que `CROP_W` e `CROP_H` sejam sempre **números pares** para evitar falhas no subsampling de chroma `YUV420p` do codificador FFmpeg H.264.
- `[RF-05]`: A rota REST `@app.route('/status')` deve retornar JSON com uso de CPU, uso de RAM, temperatura da CPU, quantidade de quadros capturados no diretório de armazenamento e espaço livre em disco em MB.

## 3. Requisitos Não-Funcionais e Performance
- `[RNF-01]`: A geração do painel composto em `generate_dashboard()` deve redimensionar e converter a cor do último quadro bruto (`ultimo_frame_bruto`) em uma cópia independente ou usando `cv2.imencode('.jpg', dashboard, [IMWRITE_JPEG_QUALITY, 70])` sem bloquear o thread principal do `logica_scanner`.
- `[RNF-02]`: O consumo de banda de rede do MJPEG stream deve ser otimizado (qualidade JPEG 70 e resolução de exibição adaptada).

---

## 4. Matriz de Impacto Multi-Plataforma

| Plataforma | Comportamento Esperado / Restrições Específicas |
| :--- | :--- |
| **Raspberry Pi 5/4 (`arm64`)** | A leitura de temperatura do processador na rota `/status` acessa `/sys/class/thermal/thermal_zone0/temp`. |
| **Mac Mini / MiniPCs (`x86_64`)** | Em sistemas Linux x86_64 genéricos, a leitura térmica em `/sys/class/thermal/` pode não existir ou usar arquivos diferentes (ex.: `thermal_zone` da CPU Intel vs acpitz). A rota `/status` deve capturar graciosamente qualquer exceção (`try/except`) e retornar `0.0` em vez de gerar erro 500. |

---

## 5. Arquitetura e Design Técnico

### 5.1. Componentes e Arquivos Modificados
- `miniola.py`: Rotas `@app.route` (`/set_crop`, `/status`, `/video_feed`) e gerador `generate_dashboard()`.
- `templates/`: Arquivos HTML/JS que consomem o MJPEG feed e enviam requisições assíncronas para calibração de corte e controle do scanner.

### 5.2. Contrato da Rota `/status` (JSON)
```json
{
  "cpu_percent": 18.4,
  "ram_percent": 32.1,
  "cpu_temp_c": 54.2,
  "frames_captured": 1420,
  "disk_free_mb": 850.5
}
```

---

## 6. Critérios de Aceitação e Plano de Verificação

### 6.1. Verificação Automatizada (`tests/`)
- [x] O script de checagem de especificações (`check_specs.py`) confirma que a SPEC-005 cumpre todos os requisitos do template.

### 6.2. Verificação Manual / Operacional
- [x] Acessar o IP do host na porta configurada exibe o dashboard atualizando a cerca de 15 FPS, com telemetria visual das perfurações em verde/vermelho.
- [x] Arrastar o seletor de crop no navegador aciona a rota `/set_crop`, atualizando o console do terminal e forçando que largura e altura sejam pares.

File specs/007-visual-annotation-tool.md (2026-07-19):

# SPEC-007: Ferramenta Interativa de Anotação Visual e Geração de Ground Truth (`tools/anotador_amostras.py`)

| Metadado | Valor |
| :--- | :--- |
| **ID da Especificação** | `SPEC-007` |
| **Status** | `Completed` |
| **Autor** | Equipe Miniola |
| **Data de Criação** | 2026-07-19 |
| **Última Atualização** | 2026-07-19 |

---

## 1. Contexto e Objetivo
O fluxo de **Spec-Driven Development (SDD)** do Miniola depende do banco de amostras (`amostras/fotogramas/` e `amostras/audio_optico/`) como *Ground Truth* para testes unitários do motor C++ (`miniola_cv.cpp`) e simulação visual no painel (`--camera mock`).

Entretanto, criar manualmente os arquivos Sidecar JSON (`.json`) digitando coordenadas de pixel `[x, y, w, h]` ou calculando a distância média entre perfurações (`pitch`) na mão é um processo tedioso, demorado e sujeito a erros humanos. 

Esta especificação formaliza a criação do **Anotador Visual Interativo (`tools/anotador_amostras.py`)**, um servidor Flask independente rodando na porta **`5001`** que serve uma interface HTML5 Canvas moderna (`tools/templates/anotador.html`). O usuário seleciona a imagem, desenha a ROI e o corte visualmente com o mouse, marca os 4 furos para cálculo automático do pitch e salva o sidecar `.json` com um clique.

## 2. Requisitos Funcionais
- `[RF-01]`: O servidor Flask em `tools/anotador_amostras.py` deve rodar em porta dedicada (`5001` por padrão ou configurável via `--port`) sem interferir no scanner principal (`miniola.py` na porta 5000).
- `[RF-02]`: O servidor deve escanear as pastas `amostras/fotogramas` e `amostras/audio_optico` e disponibilizar a rota REST `GET /api/images` retornando JSON com todas as imagens encontradas (`.png`, `.jpg`, `.jpeg`) e um indicador booleano se cada imagem já possui seu respectivo `.json` gerado.
- `[RF-03]`: A rota `GET /api/image/<path:filepath>` deve entregar o arquivo de imagem e, opcionalmente, os dados do sidecar JSON existente para permitir re-editar anotações antigas.
- `[RF-04]`: A interface web em `tools/templates/anotador.html` deve renderizar a imagem sobre um elemento `<canvas>` interativo, suportando 3 ferramentas de desenho com feedback visual em tempo real:
  - **Ferramenta ROI de Visão (Retângulo Verde)**: Define onde as 4 perfurações se encontram no quadro (`caixa_delimitadora_roi_recomendada: [x, y, w, h]`).
  - **Ferramenta de Crop do Fotograma (Retângulo Azul)**: Define a área recomendada de corte para o vídeo final (`crop_roi: [x, y, w, h]`), forçando largura e altura serem números pares se desejado ou sugerindo ajuste.
  - **Ferramenta de 4 Perfurações (Pontos Amarelos com Linhas Conectadas)**: O usuário clica sequencialmente no centro dos 4 furos. A distância vertical média em pixels `(d1 + d2 + d3) / 3` deve ser calculada instantaneamente no JavaScript e inserida no campo `pitch_px_esperado`.
- `[RF-05]`: O painel lateral deve apresentar um formulário completo sincronizado com o schema `amostras/000-template-metadata.json`, permitindo preencher `origem`, `ano_estimado`, `processo_cor`, `estoque_filme`, `bitola`, `tipo_perfuracao` e `tipo_audio`.
- `[RF-06]`: Se valores como `pitch_nominal_mm` e `encolhimento_estimado_pct` forem deixados em branco no formulário, o payload JSON os registrará explicitamente como `null` conforme as convenções do projeto para imagens empíricas (como do FilmColors).
- `[RF-07]`: A rota `POST /api/save_json` deve receber o payload formatado e gravá-lo no disco com indentação (`indent=2`) no exato caminho `amostras/<filepath_sem_extensao>.json`.

## 3. Requisitos Não-Funcionais e Performance
- `[RNF-01]`: A interface de desenho HTML5 Canvas deve responder suavemente aos eventos `mousedown`, `mousemove` e `mouseup` sem engasgos visualizando imagens de alta resolução (2K a 4K).
- `[RNF-02]`: O código de backend Flask não deve alocar recursos pesados de OpenCV no startup, mantendo o consumo de memória abaixo de 50 MB para rodar tranquilamente em background.

---

## 4. Matriz de Impacto Multi-Plataforma

| Plataforma | Comportamento Esperado / Restrições Específicas |
| :--- | :--- |
| **Mac Mini / MiniPCs (`x86_64`)** | Ambiente ideal para a etapa de curadoria e anotação. O desenvolvedor ou arquivista roda `python3 tools/anotador_amostras.py`, abre o navegador no Mac/PC local, anota imagens de alta velocidade e faz o commit dos arquivos `.json` gerados diretamente no Git. |
| **Raspberry Pi 5/4 (`arm64`)** | A ferramenta também funciona perfeitamente rodando no próprio Raspberry Pi sem interface gráfica local (modo *headless*), permitindo que o usuário acesse o IP do Pi na porta `5001` a partir de qualquer computador ou tablet na mesma rede Wi-Fi para anotar imagens capturadas pelo próprio scanner. |

---

## 5. Arquitetura e Design Técnico

### 5.1. Componentes e Arquivos Modificados
- `tools/anotador_amostras.py`: Servidor Flask leve com 4 rotas (`/`, `/api/images`, `/api/image/<path>`, `/api/save_json`).
- `tools/templates/anotador.html`: Single-page application com HTML5 Canvas e CSS puro (com tema escuro *Dark Mode* ergonômico).

### 5.2. Contrato da Rota `POST /api/save_json`
**Payload Enviado:**
```json
{
  "filepath": "fotogramas/filmcolors_1935_technicolor_01.png",
  "data": {
    "$schema": "http://json-schema.org/draft-07/schema#",
    "id": "SAMPLE-001",
    "titulo": "Anotação FilmColors 1935",
    "provenance": { ... },
    "geometry": { "pitch_nominal_mm": null, ... },
    "cv_ground_truth": {
      "caixa_delimitadora_roi_recomendada": [200, 15, 84, 830],
      "pitch_px_esperado": 194.33
    }
  }
}
```
**Resposta do Servidor (`200 OK`):**
```json
{
  "status": "success",
  "saved_path": "amostras/fotogramas/filmcolors_1935_technicolor_01.json"
}
```

---

## 6. Critérios de Aceitação e Plano de Verificação

### 6.1. Verificação Automatizada (`tests/` / `scripts/`)
- [x] O validador SDD `python3 scripts/check_specs.py` confirma a validade da `SPEC-007`.
- [x] O script `tools/anotador_amostras.py` passa por compilação sintática (`python3 -m py_compile tools/anotador_amostras.py`) sem erros de sintaxe ou dependência ausente.

### 6.2. Verificação Operacional
- [x] Ao acessar a rota `/api/images`, o servidor lista arquivos de imagem das subpastas em `amostras/` sem falhas.
- [x] Ao desenhar no canvas, calcular o pitch e enviar o formulário via POST `/api/save_json`, o arquivo `.json` é gerado fisicamente no disco no caminho especificado e com indentação limpa.

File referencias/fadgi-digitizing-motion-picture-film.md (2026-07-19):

# REF-006: FADGI Digitizing Motion Picture Film - Fluxogramas de Captação e SOW

| Metadado | Valor |
| :--- | :--- |
| **Código/Instituição** | FADGI Audio-Visual Working Group (18 de Abril de 2016) |
| **Documento Original** | `pdfs_originais/FilmScan_PWS-SOW_20160418.pdf` |
| **Destilado por** | Equipe Miniola / Antigravity |
| **Data de Resumo** | 2026-07-19 |

---

## 1. Escopo e Relevância para o Miniola
O guia da FADGI explora a complexidade de digitalizar elementos fílmicos em arquivos federais dos EUA (como a Biblioteca do Congresso e o NARA), estabelecendo um modelo de **Declaração de Trabalho (*Statement of Work - SOW*)** para definir entradas, ações recomendadas e saídas digitais em três cenários arquetípicos: películas positivas com som óptico, películas com som magnético e películas silenciosas.

Para o **Miniola**, este documento orienta a nossa arquitetura de extração de som (`SPEC-003` e `SPEC-005`), estabelecendo como o áudio óptico deve ser amostrado em sincronia com o quadro de imagem e quais são as resoluções e arquivos de entrega esperados para pacotes master de preservação (*Preservation Master Packages*).

---

## 2. Fluxos Arquetípicos de Digitalização (*Three Examples*)

A FADGI padroniza os pacotes de saída (*Deliverables*) de acordo com a natureza do elemento físico de entrada:

### Exemplo 1: Película Positiva com Som Óptico (*Positive Film, Optical Sound*)
- **Entrada**: Cópia de exibição 16mm ou 35mm (*Projection Print*) com pista de som óptico de área variável (*Variable Area*) ou densidade variável (*Variable Density*).
- **Ação Recomendada de Captura**: 
  - Varredura da imagem e da pista de som simultaneamente ou em passes dedicados.
  - A imagem deve ser capturada em toda a largura útil, preferencialmente incluindo a pista de som em alta resolução geométrica para que a decodificação digital por software (*Optical Sound Decoding via Image*) seja viável e reversível.
- **Saídas Digitais (*Outputs*)**:
  1. **Preservation Master Image**: Sequência de arquivos DPX 10-bit Log (`SMPTE ST 268`) em resolução `2K` ou `4K`.
  2. **Preservation Master Audio**: Arquivo WAV não comprimido (`Broadcast WAVE - BWF`), `24-bit / 96 kHz` (ou `48 kHz` mínimo), sincronizado com o código de tempo da imagem.
  3. **Mezzanine / Intermediário**: Arquivo Apple ProRes 422 HQ ou 4444 unificando imagem e áudio sincronizado para edição/restauração.
  4. **Access Copy**: MP4 (H.264 / AAC) leve para visualização web.

### Exemplo 2: Película com Som Magnético (*Double-System or Composite Mag Sound*)
- **Entrada**: Película com pista magnética colada na borda (*Stripe*) ou som magnético em rolo separado sincronizado (*Sepmag / Fullcoat*).
- **Ação Recomendada**: Varredura por cabeçote magnético calibrado conforme curva de equalização da época, gerando BWF de `24-bit / 96 kHz` isolado de ruídos mecânicos de tração.
> **Nota de Escopo do Miniola**: A extração de som magnético é descrita aqui para completude da norma FADGI. No entanto, o **Miniola foca exclusivamente na extração de som óptico via visão computacional (`SPEC-003`)**, sem suporte nativo ou cabeçote magnético a princípio.

### Exemplo 3: Película Positiva Silenciosa (*Positive Film, Silent*)
- **Entrada**: Película 16mm, 35mm ou 8mm sem pista sonora (ex.: cinema mudo ou tomadas de arquivo/rushes).
- **Ação Recomendada**: Captura no modo *Overscan* de borda a borda para preservar anotações de montagem, tintura (*tinting/toning*) e marcações de cadência da câmera original na taxa nominal de quadros histórica (`14 FPS` a `24 FPS`).

---

## 3. Diretrizes para Extração de Áudio Óptico no Miniola (`SPEC-003`)
1. **Varredura Óptica 1D / 2D**:
   - Se o scanner realiza a leitura do áudio óptico através de uma câmera de área (como a Ximea do Miniola iluminando a coluna da pista sonora), a resolução horizontal da pista de som (`audio_w`) e a uniformidade de iluminação da fenda são críticas para evitar distorção harmônica (*THD*).
2. **Sincronia Imagem-Áudio (*Lip-Sync Advance*)**:
   - Em projetores e leitores analógicos 35mm, o cabeçote de som óptico fica posicionado **20 ou 21 quadros à frente** da janela de projeção da imagem (e **26 quadros à frente** em 16mm).
   - O nosso motor C++ (`miniola_cv.cpp`) ou pipeline assíncrono em Python deve registrar com precisão matemática o deslocamento temporal entre a fatia de áudio lida (`audio_chunk`) e o quadro visual correspondente na fila `fila_gravacao`.

---

## 4. Especificações de SDD Vinculadas (`specs/`)
- `[SPEC-003](../specs/003-optical-audio-extraction.md)` - Extração computacional de som óptico com costura contínua e compensação de velocidade do filme.
- `[SPEC-005](../specs/005-web-dashboard-routing.md)` - Roteamento dos pacotes de saída (*Deliverables*) para download na interface do usuário (RAW vs ProRes/MP4).

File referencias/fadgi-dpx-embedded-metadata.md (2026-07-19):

# REF-005: FADGI DPX Embedded Metadata - Diretrizes para Cabeçalhos (`SMPTE ST 268`)

| Metadado | Valor |
| :--- | :--- |
| **Código/Instituição** | FADGI Audio-Visual Working Group (23 de Abril de 2019) / SMPTE ST 268-1 |
| **Documento Original** | `pdfs_originais/DPX_Embed_Guideline_20190423.pdf` |
| **Destilado por** | Equipe Miniola / Antigravity |
| **Data de Resumo** | 2026-07-19 |

---

## 1. Escopo e Relevância para o Miniola
O formato **DPX (*Digital Moving-Picture Exchange*)**, padronizado pela `SMPTE ST 268-1`, é o formato de arquivo padrão mundial para digitalização e preservação master de fotogramas de película cinematográfica sem compressão. As diretrizes da FADGI padronizam o preenchimento dos blocos de metadados binários fixos (*Generic Section* e *Motion Picture Section*) dentro do cabeçalho de cada arquivo DPX (os primeiros `2048 bytes`).

Para o **Miniola**, este documento fornece o mapa exato de quais campos binários e metadados ASCII devem ser populados quando exportarmos quadros individuais ou sequências DPX a partir da nossa fila assíncrona (`fila_gravacao`), garantindo interoperabilidade com arquivos nacionais e internacionais de cinema.

---

## 2. Blocos de Cabeçalho e Campos Críticos FADGI

A FADGI divide o cabeçalho DPX em duas grandes seções obrigatórias para preservação de patrimônio:

### 2.1. Seção Genérica do Arquivo (*File Information & Image Information*)
| Offset / Campo DPX | Tipo / Tamanho | Especificação FADGI / Prática Miniola |
| :--- | :--- | :--- |
| `Magic Number` (0x00) | 4 bytes (`SDPX` ou `XPDS`) | Define o *Byte Order* (`Big-Endian` ou `Little-Endian`). Miniola exporta em `Big-Endian` (`SDPX`). |
| `Image Offset` (0x04) | 4 bytes inteiro | Padrão fixado em `2048 bytes` (ou `8192 bytes` se incluir *User Data* longo). |
| `Version Header` (0x08) | 8 bytes ASCII | Deve ser preenchido como `V1.0` ou `V2.0` (sem espaços extras truncados com nulos). |
| `File Name` (0x24) | 100 bytes ASCII | Nome exato do arquivo (ex.: `SDK01473_20260719_0001024.dpx`). |
| `Creation Date/Time` (0x88) | 24 bytes ASCII | Formato ISO `YYYY:MM:DD:HH:MM:SS:LTZ` representando o instante real da captura no scanner. |
| `Creator` (0xA0) | 100 bytes ASCII | Nome da instituição e do sistema (ex.: `Miniola Scanner / Cinemateca`). |
| `Project Name` (0x104) | 200 bytes ASCII | Identificador do projeto de preservação ou do título do filme (`film_metadata.film_title`). |
| `Bit Depth` | Inteiro | Para preservação, padronizado em **10-bit Log** (`Cineon`) ou **12/16-bit Linear**. |

### 2.2. Seção Específica de Cinema (*Motion Picture Film Information Section*)
Esta seção do cabeçalho DPX armazena a proveniência fotoquímica e mecânica do fotograma:

| Campo DPX (Motion Picture) | Tamanho ASCII | Diretriz de Preenchimento do Miniola |
| :--- | :--- | :--- |
| `Film Mfr ID` | 2 bytes | Código de dois caracteres do fabricante da película (ex.: `01` para Kodak, `02` para Fuji, `03` para Agfa/Gevaert). Extraído via leitura do *Edge Code*. |
| `Film Type` | 2 bytes | Identificador da emulsão (ex.: `5247` ou `5222`). |
| `Offset in Perfs` | 2 bytes inteiro | Número do furo em relação ao quadro (ex.: `1` a `4` em 35mm). |
| `Prefix / Count` | 6 + 4 bytes | O número de borda (*Keykode / Edge Number*) legível na lateral do filme. |
| `Frame Rate of Original` | Float (4 bytes) | Taxa de quadros nominal da película de origem (ex.: `16.0` ou `24.0` FPS). |
| `Shutter Angle` | Float (4 bytes) | Em scanners digitais contínuos como o Miniola, preenchido como `360.0` ou `0.0`. |
| `Frame Identification` | 32 bytes ASCII | Identificador único serial da sequência ou rolo digitalizado (`rolo_01_reel`). |

---

## 3. Diretrizes de Empacotamento de Pixels (*Packing & Alignment*)
1. **Alinhamento de Palavra de 32 bits (*Method A vs. Method B*)**:
   - Para arquivos **10-bit log**, 3 canais R, G, B consomem 30 bits. Os 2 bits restantes em cada palavra de 32 bits (*DWORD*) não devem conter dados de imagem (*Padding bits* em zero).
   - O Miniola deve certificar que o empacotamento em C++ via `miniola_cv.cpp` ou bibliotecas Python de exportação DPX não divida amostras de um mesmo pixel através dos limites da palavra de 32 bits (`Packing Method 1`).
2. **Razão de Aspecto de Pixel (`Pixel Aspect Ratio`)**:
   - Deve ser explicitamente registrada como `1:1` (`Horizontal=1`, `Vertical=1`) para sensores digitais quadrados, evitando distorções anamórficas não intencionais na exibição.

---
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

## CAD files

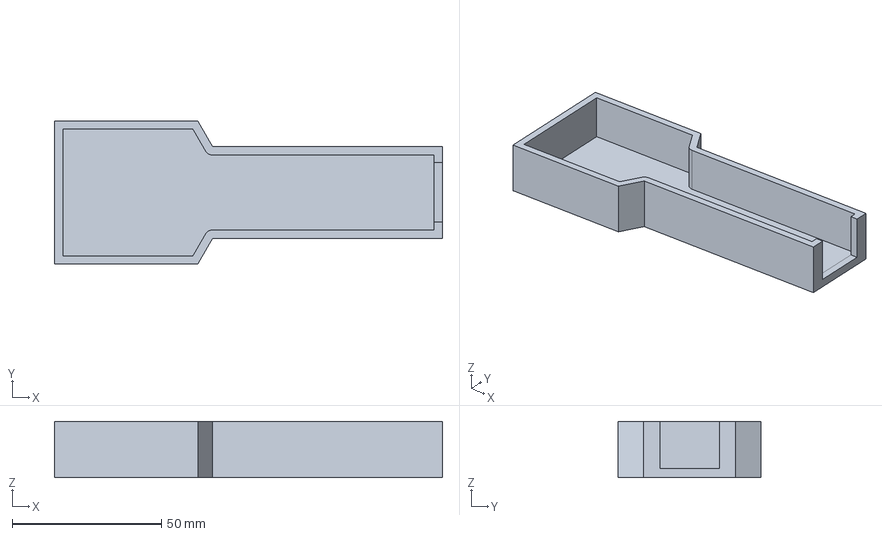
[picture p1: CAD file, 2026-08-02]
stl/braco_motor.FCStd
130.0 x 48.0 x 18.9 mm

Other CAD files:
stl/braco_motor-Corpo.step

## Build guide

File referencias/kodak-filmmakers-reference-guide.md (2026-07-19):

# REF-008: Kodak Essential Reference Guide for Filmmakers - Estrutura da Película e Emulsão

| Metadado | Valor |
| :--- | :--- |
| **Código/Instituição** | Eastman Kodak Company (Motion Picture Film Group) |
| **Documento Original** | `pdfs_originais/kodak-essential-reference-guide-for-filmmakers.pdf` |
| **Destilado por** | Equipe Miniola / Antigravity |
| **Data de Resumo** | 2026-07-19 |

---

## 1. Escopo e Relevância para o Miniola
O *Essential Reference Guide for Filmmakers* da Kodak é a Bíblia técnica da fabricação e estrutura de filmes cinematográficos. Ele detalha a composição física do suporte (Acetato vs. Poliéster), o comportamento dos cristais de haleto de prata na emulsão (*T-Grain*), curvas sensitométricas de densidade característica (curva H&D) e o sistema de identificação por códigos de borda (*Keykode*).

Para o **Miniola**, compreender a física das camadas de emulsão e o índice de refração dos suportes Kodak orienta a calibração de exposição e limiar (*Threshold*) da nossa binarização em C++ (`miniola_cv.cpp`), além de explicar por que certos filmes coloridos envelhecidos exigem ajuste de densidade diferencial ou luz difusa na mesa.

---

## 2. Parâmetros Críticos e Estrutura Física do Suporte

A Kodak categoriza as bases físicas das películas cinematográficas em dois grandes grupos:

| Propriedade / Camada | Triacetato de Celulose (*Acetate Base*) | ESTAR / Poliéster (*Polyester Base*) | Impacto e Tratamento no Miniola |
| :--- | :--- | :--- | :--- |
| **1. Espessura da Base (*Base Thickness*)** | Negativos e Reversíveis de Câmera: `~0.13 mm` (`5.2 mils`).<br>Cópias de Exibição: `~0.14 mm` (`5.5 mils`). | Negativos/Intermediários e Cópias ESTAR: `~0.10 mm` (`4.0 mils`) a `0.12 mm` (`4.7 mils`). | A variação de espessura de `0.10 mm` a `0.14 mm` altera sutilmente o plano focal. O nosso suporte de lente com rosca fina permite foco micrométrico ajustável (`foco_atual`). |
| **2. Resistência Mecânica e Tração** | Suporte que rasga com facilidade sob tensão. Ao envelhecer em ambientes úmidos, sofre hidrólise ácido-catalisada (*Síndrome do Vinagre*), causando encolhimento severo e empenamento (*buckling*). | Suporte extremamente resistente a rasgos (*High Tensile Strength*). Não sofre Síndrome do Vinagre nem encolhimento significativo com o tempo. | **Alerta Crítico**: Filmes ESTAR nunca devem passar por projetores ou scanners com pinos dentados travados, pois, em caso de engasgo, arrebentarão o próprio mecanismo em vez de rasgar o filme. O Miniola é ideal para ESTAR e Acetato por usar roletes lisos (*sprocketless*). |
| **3. Camada Antialo (*Rem-Jet / Anti-Halation Undercoat*)** | Camada preta de carbono no verso (*Rem-Jet*) em negativos de cor para evitar reflexos da luz na base durante a exposição na câmera, removida no banho alcalino inicial do laboratório. | Camada anti-halo e anti-estática transparente ou acinzentada embutida ou no verso, otimizada para transporte limpo em laboratórios de alta velocidade. | Se um filme não processado (ou mal lavado) contiver resíduos de *Rem-Jet* no verso, a leitura de luz por transparência na fenda do Miniola será obstruída. |
| **4. Códigos de Borda (*Keykode / Edge Numbers*)** | Código de barras latente e numeração humanamente legível gravados a cada 0.5 pé (`64 perfurações` em 35mm / `20 perfurações` em 16mm) com informações de lote, rolo e ano. | Idem, com sufixo ou marcação de suporte ESTAR (`E`). | Nosso Anotador e exportador DPX (`REF-005`) devem capturar e registrar essa numeração no campo `Prefix / Count` para rastreabilidade de montagem. |

---

## 3. Curvas Sensitométricas e Camadas de Emulsão
1. **Curva Característica (Hurter & Driffield - H&D)**:
   - Relaciona o Logaritmo da Exposição (`Log E`) no eixo X com a Densidade Óptica (`D`) no eixo Y.
   - Divide-se em 3 regiões: **Pé (*Toe*)** (sombras, menor contraste), **Trecho Linear (*Straight-Line Portion*)** (gama de contraste proporcional da imagem) e **Ombro (*Shoulder*)** (altas luzes, saturação dos cristais).
   - O nosso scanner deve capturar desde o piso do *Toe* (`Dmin` da máscara de cor laranja em filmes Kodak `5219/5207`) até o topo do *Shoulder* (`Dmax`), sem clipar o canal azul (que possui maior densidade na máscara integral).
2. **Cristais T-Grain (Kodak Vision/Vision3)**:
   - Cristais planos em formato tabular (*Tabular Grains*) que oferecem maior captura de luz por volume de prata, reduzindo a granulação em emulsões de alta sensibilidade (`500T`).

---

## 4. Especificações de SDD Vinculadas (`specs/`)
- `[SPEC-001](../specs/001-vision-engine-cpp.md)` - Algoritmo de binarização com limiar dinâmico que se adapta à densidade base (`Dmin`) do acetato ou poliéster.
- `[SPEC-007](../specs/007-ground-truth-annotator.md)` - Documentação da bitola, encolhimento e estado física (Síndrome do Vinagre / empenamento) com base nos parâmetros metrológicos da Kodak.

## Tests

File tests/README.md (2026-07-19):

# Framework de Testes de Bancada e Validação SDD (`tests/`)

Este diretório contém a suíte de testes automatizados e sintéticos do **Miniola**, desenvolvida para permitir a validação do fluxo de **Spec-Driven Development (SDD)** no seu PC Linux local (como Mac Mini Late 2012 x86_64 ou MiniPCs) sem a necessidade de hardware físico (câmera ou Raspberry Pi acoplados).

## Objetivos
- Verificação rápida do motor C++ (`miniola_cv`) usando quadros sintéticos (`mock`).
- Garantir conformidade com as especificações [SPEC-001](../specs/001-vision-engine-cpp.md) e [SPEC-006](../specs/006-multiplatform-minipc-support.md).
- Execução em Integração Contínua (CI) no GitHub Actions (`.github/workflows/sdd-validate.yml`).

## Como Executar

```bash
# A partir da raiz do projeto, com o ambiente virtual ativo:
python3 -m unittest discover -s tests -v
```

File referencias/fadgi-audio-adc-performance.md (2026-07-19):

# REF-007: FADGI Audio ADC Performance - Especificações de Conversores Analógico-Digitais

| Metadado | Valor |
| :--- | :--- |
| **Código/Instituição** | FADGI Audio-Visual Working Group (2016 v1.1 & Setembro 2017 - Low Cost) |
| **Documentos Originais** | `pdfs_originais/ADC_performGuide_v1-1_20160216.pdf` e `ADC_Low_Cost_performGuide_2017-09-30.pdf` |
| **Destilado por** | Equipe Miniola / Antigravity |
| **Data de Resumo** | 2026-07-19 |

---

## 1. Escopo e Relevância para o Miniola
A FADGI estabelece métricas e métodos de ensaio rigorosos para conversores analógico-digitais (ADC) utilizados na preservação de áudio patrimonial, dividindo as especificações em duas categorias: **High Level Performance** (para estúdios e arquivos de referência) e **Low Cost Guideline** (para instituições com orçamento limitado, mas que exigem fidelidade de preservação sem distorções severas).

Para a **Miniola**, este documento orienta a nossa extração de som (`SPEC-003`) nas tolerâncias equivalentes exigidas para o processamento de som óptico por visão computacional em C++ (`miniola_cv.cpp`).

---

## 2. Parâmetros Críticos e Tabelas Comparativas (High Level vs. Low Cost)

A tabela abaixo sintetiza os limites de desempenho exigidos em testes padronizados para conversões em `24-bit / 96 kHz` (e mínimas em `48 kHz`):

| Parâmetro / Ensaio | FADGI High Level Performance (v1.1) | FADGI Low Cost Guideline (2017) | Relevância e Aplicação no Miniola |
| :--- | :--- | :--- | :--- |
| **1. Resposta em Frequência (*Frequency Response*)** | `20 Hz - 20 kHz`: `±0.1 dB`<br>`20 Hz - 40 kHz`: `±0.3 dB` (para `96 kHz`) | `20 Hz - 20 kHz`: `±0.5 dB`<br>`20 Hz - 40 kHz`: `±1.0 dB` | A extração óptica por câmera no Miniola é limitada pela largura da fenda em pixels (`slit_y`) e pela velocidade do filme. O nosso filtro óptico não deve atenuar frequências de voz (`100 Hz - 5 kHz`) além de `±0.5 dB`. |
| **2. Distorção Harmônica Total + Ruído (*THD+N*)** | `≤ -105 dB` (`0.00056%`) a 1 kHz (`-1 dBFS`) | `≤ -90 dB` (`0.00316%`) a 1 kHz (`-1 dBFS`) | A costura de quadros da pista óptica em C++ deve manter a distorção harmônica no limiar *Low Cost* (`≤ -90 dB`), garantindo varredura limpa sem zumbidos ou artefatos de junção. |
| **3. Alcance Dinâmico / Sinal-Ruído (*Dynamic Range / SNR*)** | `≥ 115 dB` (ponderado A ou não ponderado a `20-20 kHz`) | `≥ 100 dB` (ponderado A ou não ponderado a `20-20 kHz`) | Para a captação de som óptico (área variável ou densidade variável), a uniformidade de luz na fenda e a binarização do sensor devem garantir um piso de ruído de pelo menos `100 dB` abaixo do pico. |
| **4. Diafonia (*Cross-Talk*)** | `≤ -110 dB` entre canais (`20 Hz - 20 kHz`) | `≤ -85 dB` entre canais (`20 Hz - 20 kHz`) | Ao digitalizar trilhas ópticas duplas/bilaterais ou estéreo óptico, o vazamento de amostragem de pixels de um canal para o outro no sensor não pode ultrapassar `-85 dB`. |
| **5. Rejeição de Interferência Digital / Ruído** | `≥ 80 dB` (`20 Hz - 20 kHz`) | `≥ 60 dB` (`20 Hz - 20 kHz`) | Essencial para garantir que flutuações de luminosidade ou interferências eletromagnéticas dos motores de passo do Miniola não interfiram no sensor da câmera que lê a pista óptica. |

---

## 3. Diretrizes de Teste e Calibração para Som Óptico
- **Sinais de Teste (*Test Signals*)**: Os ensaios de conformidade da FADGI utilizam ondas senoidais puras de `1 kHz` a `-1 dBFS` para THD+N e varreduras (*sweeps*) logarítmicas de `20 Hz a 40 kHz` para resposta em frequência, que servem como padrão ouro para calibrar a decodificação da nossa câmera.
- **Iluminação Uniforme da Fenda**: Como o Miniola extrai o som exclusivamente por via **óptica** computacional (`SPEC-003`), a fenda luminosa LED sobre a trilha sonora deve ter brilho rigorosamente constante e sem cintilação (*flicker-free*), evitando que o ruído de alimentação USB/PWM se transforme em ruído na conversão de áudio.

---

## 4. Especificações de SDD Vinculadas (`specs/`)
- `[SPEC-003](../specs/003-optical-audio-extraction.md)` - Algoritmo de extração 1D/2D em C++ para garantir que a costura (*stitching*) de áudio óptico não introduza ruído harmônico ou saltos de fase que violem os limites de *THD+N*.

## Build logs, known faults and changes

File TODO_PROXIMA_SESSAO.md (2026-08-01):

# Roadmap & Checklist para Próxima Sessão (Miniola)

Este documento centraliza a varredura arquitetural e técnica do repositório **Miniola**, definindo as prioridades de refatoração, conformidade multi-plataforma e melhorias de performance para a próxima sessão de desenvolvimento.

---

## 1. Provedores de Câmera (`cameras/`) [SPEC-002 & SPEC-006]

- [ ] **1.1. Implementar Provedor `uvc` (`cameras/uvc.py`)**:
  - Criar classe `UVCCameraAdapter(CameraProvider)` utilizando `cv2.VideoCapture(index, cv2.CAP_V4L2)` para permitir que qualquer webcam ou câmera industrial USB genérica conecte no Mac Mini ou PC Linux sem depender do SDK da Ximea.
- [ ] **1.2. Implementar Provedor `mock` (`cameras/mock.py`)**:
  - Criar classe `MockCameraProvider(CameraProvider)` capaz de gerar quadros sintéticos contínuos a 120 FPS (com perfurações animadas descendo pela ROI e fenda de áudio de teste) ou reproduzir um arquivo de vídeo preliminar (`playback`). Isso permitirá testar gatilhos, rotas web e gravação assíncrona em PCs de desenvolvimento sem nenhum hardware conectado.
- [ ] **1.3. Otimizar Seletor Dinâmico (`cameras/__init__.py`)**:
  - Evitar importações incondicionais no topo (`from .pi import PiCameraAdapter`), carregando os módulos sob demanda via `get_camera_provider(name)` para que sistemas `x86_64` não tentem checar dependências exclusivas de Raspberry Pi na inicialização.

---

## 2. Modularização e Desacoplamento do Core (`miniola.py`) [SPEC-005]

- [ ] **2.1. Extrair Servidor Web/Dashboard (`web/` ou `routes.py`)**:
  - O arquivo `miniola.py` possui mais de 880 linhas englobando visão computacional, fila IPC, terminal interativo e rotas do Flask. Isolar as rotas (`/video_feed`, `/status`, `/cmd`, `/status_stream`) e o gerador de streaming em um módulo dedicado melhorará a manutenibilidade e a clareza.
- [ ] **2.2. Extrair Worker de Gravação Assíncrona (`workers/recorder.py`)**:
  - Mover `processo_escrita_disco(fila_in)` e funções de encerramento de sessão de áudio óptico (`abrir_sessao_audio_optico`, `fechar_sessao_audio_optico`) para um módulo trabalhador isolado (`workers/`), reforçando o desacoplamento entre o loop de captura de alta prioridade (`Core 0/1`) e o loop de I/O em disco (`Core 2/3`).

---

## 3. Inteligência de Pós-Processamento (`process.py`) [SPEC-001 & SPEC-004]

- [ ] **3.1. Detecção Automática do Tipo de Obturador nos Metadados**:
  - Atualmente, para evitar distorção vertical de *breathing* em câmeras Global Shutter (`Ximea`), o usuário ou script passa a flag `--disable-rs-comp` ao acionar o `process.py`. Inserir o campo `"shutter_type": "global" | "rolling"` no cabeçalho dos arquivos `miniola_tracking_{sid}.jsonl` para que o `process.py` aplique a compensação de Rolling Shutter automaticamente apenas quando necessário.
- [ ] **3.2. Validação da Pipeline de Áudio Óptico (Filtro Anti-Aliasing Slit)**:
  - Adicionar testes automatizados cobrindo a conversão e interpolação cúbica (`CubicSpline`) do áudio óptico de densidade variável e área variável gerado nos arquivos `.f32` sidecar.

---

## 4. Expansão da Suíte de Testes (`tests/`) e SDD

- [ ] **4.1. Testes de Concorrência e Isolamento de Buffer**:
  - Criar teste unitário em `tests/` que simule leituras concorrentes em threads separadas para garantir que o `.copy()` no retorno dos provedores de câmera evite condições de corrida (*race conditions*) contra a conversão do OpenCV/Flask.
- [ ] **4.2. Benchmark de Gravação Assíncrona (`libjpeg-turbo`)**:
  - Criar teste de estresse em `tests/` que enfileire 300 quadros BGR na `multiprocessing.Queue` e meça o tempo de vazão via `cv2.imwrite`, garantindo que o tempo médio permaneça estritamente abaixo do limite de 5 milissegundos por fotograma (`[RNF-02]` da `SPEC-004`).
- [ ] **4.3. Criação de Especificação para Ferramenta de Anotação (`specs/007-visual-annotation-tool.md`)**:
  - Revisar e completar a especificação `SPEC-007` (caso esteja em rascunho ou pendente de expansão) para cobrir a interface de anotação visual de defeitos de filme.

---

## 5. Referências e Padrões (`referencias/`)

- [ ] **5.1. Mapeamento de Normas na Documentação**:
  - Conectar explicitamente os parâmetros de áudio óptico (notch de 90Hz/180Hz, passa-baixa de 7kHz no `process.py`) com os documentos `referencias/fadgi-audio-adc-performance.md` e `referencias/kodak-filmmakers-reference-guide.md` em notas explicativas ou na `SPEC-003`.

---

## 6. Redesign Profissional de UI/UX do Dashboard (`templates/index.html` & `miniola.py`) [SPEC-005]

A interface web atual (`index.html` e `generate_dashboard`) foi construída como um mosaico rígido de buffers OpenCV combinados verticalmente/horizontalmente (`np.vstack` / `np.hstack`). Para elevar o Miniola ao nível dos softwares de scanners profissionais de arquivo (como **Blackmagic Cintel**, **Lasergraphics ScanStation/Director** e **DFT Scanity/Spirit**), implementaremos um redesign visual completo:

- [ ] **6.1. Correção da Distorção da Imagem da Zebra**:
  - **Diagnóstico**: Atualmente em `miniola.py` (linha 715), o frame da Zebra (`ultimo_crop_preview`) é forçado para as dimensões estáticas de `(100, 280)px`. Isso esmaga e estica verticalmente qualquer proporção de corte na tela.
  - **Solução**: Modificar a renderização da Zebra para preservar estritamente a proporção de aspecto natural da película (`aspect ratio` calculado dinamicamente ou mantendo escala uniforme `min(ratio_w, ratio_h)`). Além disso, permitir que a Zebra seja ativada como um **overlay comutável (*toggle button*)** diretamente por cima do feed de vídeo principal de alta resolução, como ocorre nos monitores do Cintel e do DaVinci Resolve.
- [ ] **6.2. Arquitetura de Layout Baseada em Scopes Profissionais (GUI/UX)**:
  - **Desacoplamento do Mosaico OpenCV (`display: grid`)**: Em vez de gerar um único blocão JPEG gigante no Python com todos os painéis grudados, desmembrar o dashboard em componentes independentes no `templates/index.html` utilizando **CSS Grid / Flexbox responsivo**:
    - **Viewport Principal (Film Gate View)**: Centralizado, com guias de enquadramento limpas (*Framing Guides* profissionais: 4-perf 35mm, 3-perf, 16mm Academy) e indicadores de foco/exposição.
    - **Painel de Scopes de Engenharia (Luminance Histogram & Waveform)**: Redesenhar o histograma com escala logarítmica/linear clara, marcações de IRE (0 a 100 IRE / 0 a 255 8-bit / 10-bit), e gradiente de cor de advertência de clipping (vermelho nos extremos 0 e 255, verde na zona segura).
    - **Painel de Áudio Óptico (Optical Sound Track & VU Meter)**: Exibir a tira cinza da trilha de áudio com indicador de balanço lateral e medidor visual de pico de modulação.
- [ ] **6.3. Padronização de Design System (Cores, Fontes e Ergonomia de Estúdio)**:
  - **Paleta Dark Pro**: Adotar uma paleta cinza-escuro neutra e de alto contraste inspirada em softwares de color grading/telecine (`#181818` para o fundo da janela, `#262626` para cards de painel, `#3a3a3a` para bordas de contenção, `#00d26a` para status OK/Safe, e `#ff3333` para gravação ativa `REC`).
  - **Tipografia Técnica e Legível**: Padronizar as fontes utilizando famílias modernas e limpas via Google Fonts ou variáveis CSS (`Inter` / `Outfit` para a interface geral, e `JetBrains Mono` ou `Roboto Mono` para telemetria numérica, FPS, temperatura e posições XY de crop).
  - **Controle de Transporte (*Transport Console*)**: Redesenhar a barra de botões inferiores em estilo console físico (Botão `REC` vermelho pulsante bem nítido, `PAUSE`, controles milimétricos de Crop, e botões táteis para alteração de padrão Bayer `0-3` e ganho/exposição do sensor ao vivo sem precisar digitar no terminal).

---

## 7. Fase 2: Transporte Motorizado (Dual Motor & PID) [SPEC-010]

O teste de bancada de inicialização via USB e UART do motor X foi concluído com sucesso utilizando firmware C++ via SKR Pico. O foco agora é implementar a tração de rolo a rolo.

- [ ] **7.1. Montagem Mecânica Físíca (Hardware)**:
  - Conectar os dois motores NEMA 17 aos pratos de Feed-in e Take-up e acoplar a película de teste para validação física da tração.
- [ ] **7.2. Firmware C++ de Tensão (SKR Pico)**:
  - Habilitar o Eixo Y no `main.cpp` e configurar as interrupções de leitura de carga mecânica via tecnologia **StallGuard 4** dos drivers TMC2209. Cortar a energia (Safety Stop) instantaneamente caso a carga lida indique travamento ou enrosco do filme.
- [ ] **7.3. Controlador PID Python (`motor_controller.py`)**:
  - Implementar a "Mola Matemática" (Loop PID). O controlador deverá receber a medição de FPS (perfurações) do `miniola_cv.cpp` e enviar comandos diferenciais seriais de velocidade para ajustar a aceleração dos motores X e Y, compensando em tempo real a mudança de diâmetro dos rolos conforme o filme passa.

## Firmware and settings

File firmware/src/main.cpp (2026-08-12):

#include <Arduino.h>
#include <TMCStepper.h>

// --- PINOUT DA SKR PICO V1.0 (RP2040) ---
// Eixo X (Feed-in / Freio Sutil)
#define X_STEP_PIN 11
#define X_DIR_PIN 10
#define X_EN_PIN 12

// Eixo Y (Take-up / Puxador Principal)
#define Y_STEP_PIN 6
#define Y_DIR_PIN 5
#define Y_EN_PIN 7

// Eixo Z (Atuador de Foco)
#define Z_STEP_PIN 19
#define Z_DIR_PIN 28
#define Z_EN_PIN 2

// UART Compartilhada dos Drivers (Serial2 no Arduino-Pico)
#define UART_RX_PIN 9
#define UART_TX_PIN 8

// Porta de Potência para Iluminação (Heater 0)
#define LED_PIN 23

// Encoder Rotativo E38S6G5-600B-G24N (Pinos de UART sem filtro RC)
#define ENCODER_PIN_A 0 // GP0 (UART0 TX no Header Raspberry Pi)
#define ENCODER_PIN_B 1 // GP1 (UART0 RX no Header Raspberry Pi)

volatile long int encoder_pulses = 0;
volatile int last_encoded = 0;

void update_encoder() {
  // Substituímos o digitalRead lento pela leitura direta no registrador do
  // RP2040 (gpio_get)
  int MSB = gpio_get(ENCODER_PIN_A);
  int LSB = gpio_get(ENCODER_PIN_B);

  int encoded = (MSB << 1) | LSB;
  int sum = (last_encoded << 2) | encoded;

  if (sum == 0b1101 || sum == 0b0100 || sum == 0b0010 || sum == 0b1011)
    encoder_pulses++;
  if (sum == 0b1110 || sum == 0b0111 || sum == 0b0001 || sum == 0b1000)
    encoder_pulses--;

  last_encoded = encoded;
}

// Endereços UART (Na SKR Pico V1.0, X=0, Z=1, Y=2, E0=3)
#define DRIVER_ADDRESS_X 0b00 // 0
#define DRIVER_ADDRESS_Z 0b01 // 1
#define DRIVER_ADDRESS_Y 0b10 // 2 (ESTE ERA O BUG!)
#define R_SENSE 0.11f

// Instâncias dos Drivers
TMC2209Stepper driverX(&Serial2, R_SENSE, DRIVER_ADDRESS_X);
TMC2209Stepper driverY(&Serial2, R_SENSE, DRIVER_ADDRESS_Y);
TMC2209Stepper driverZ(&Serial2, R_SENSE, DRIVER_ADDRESS_Z);

// --- VARIÁVEIS DE ESTADO E CONTROLE ---
bool is_moving = false;
bool manual_mode = false;
bool safety_stop_triggered = false;

// Velocidade Alvo e Atual (Hz) para Rampa de Aceleração
long target_speed_X = 0;
long target_speed_Y = 0;
long target_speed_Z = 0;
long current_speed_X = 0;
long current_speed_Y = 0;
long current_speed_Z = 0;
unsigned long last_accel_time = 0;

// Variáveis para controle não-bloqueante de passos (micros())
unsigned long last_step_time_X = 0;
unsigned long last_step_time_Y = 0;
unsigned long last_step_time_Z = 0;
unsigned long step_interval_X = 0;
unsigned long step_interval_Y = 0;
unsigned long step_interval_Z = 0;

// StallGuard Threshold
const int SG_THRESHOLD_Y =
    50; // Limiar de tensão. Abaixo disso = filme travado. Ajustável depois.
unsigned long last_sg_check = 0;

void setup() {
  Serial.begin(115200);
  delay(2000); // Aguarda host montar a porta USB

  pinMode(X_STEP_PIN, OUTPUT);
  pinMode(X_DIR_PIN, OUTPUT);
  pinMode(X_EN_PIN, OUTPUT);
  pinMode(Y_STEP_PIN, OUTPUT);
  pinMode(Y_DIR_PIN, OUTPUT);
  pinMode(Y_EN_PIN, OUTPUT);
  pinMode(Z_STEP_PIN, OUTPUT);
  pinMode(Z_DIR_PIN, OUTPUT);
  pinMode(Z_EN_PIN, OUTPUT);

  // Configuração do Encoder
  pinMode(ENCODER_PIN_A, INPUT_PULLUP);
  pinMode(ENCODER_PIN_B, INPUT_PULLUP);
  attachInterrupt(digitalPinToInterrupt(ENCODER_PIN_A), update_encoder, CHANGE);
  attachInterrupt(digitalPinToInterrupt(ENCODER_PIN_B), update_encoder, CHANGE);

  // Inicia motores desligados
  digitalWrite(X_EN_PIN, HIGH);
  digitalWrite(Y_EN_PIN, HIGH);
  digitalWrite(Z_EN_PIN, HIGH);

  // Configuração e desligamento inicial do Painel de LED
  pinMode(LED_PIN, OUTPUT);
  analogWriteFreq(10000); // 10kHz (Tentativa de limite superior seguro para o MOSFET)
  analogWrite(LED_PIN, 0);

  // Inicializa a UART (Serial2)
  Serial2.setRX(UART_RX_PIN);
  Serial2.setTX(UART_TX_PIN);
  Serial2.begin(115200);
  delay(500);

  // Configuração Driver X (Feed-in)
  driverX.begin();
  driverX.toff(5);
  driverX.rms_current(800,
                      0.0); // Aumentado para 200mA para garantir torque suave
  driverX.microsteps(16);
  driverX.pwm_autoscale(true);
  driverX.en_spreadCycle(false); // StealthChop

  // Configuração Driver Y (Take-up)
  driverY.begin();
  driverY.toff(5);
  driverY.rms_current(
      1000, 0.0); // Aumentado para 1A (Torque Brutal) para esmagar os trancos
  driverY.microsteps(16);
  driverY.pwm_autoscale(true);
  driverY.en_spreadCycle(
      false); // Desativa StealthChop para garantir torque máximo contínuo

  // Configura o StallGuard no Motor Y
  driverY.TCOOLTHRS(0xFFFFF); // Habilita medição SG em baixa velocidade
  driverY.SGTHRS(50);         // Sensibilidade do StallGuard (0-255)

  // Configuração Driver Z (Foco da Câmera - Motor 28BYJ-48)
  driverZ.begin();
  driverZ.toff(5);
  driverZ.rms_current(250, 0.0); // 250mA (Baixo torque para não esquentar)
  driverZ.microsteps(16);
  driverZ.pwm_autoscale(true);
  driverZ.en_spreadCycle(false); // Mantém StealthChop para silêncio absoluto

  // Liga as saídas de potência
  digitalWrite(X_EN_PIN, LOW);
  digitalWrite(Y_EN_PIN, LOW);
  digitalWrite(Z_EN_PIN, HIGH); // Z começa desligado para não aquecer à toa

  Serial.println("Miniola Dual-Motor Firmware Iniciado (PID Ready)");
}

void parse_serial_command() {
  static String cmd_buffer = "";
  while (Serial.available() > 0) {
    char c = Serial.read();
    if (c == '\n') {
      String cmd = cmd_buffer;
      cmd_buffer = "";
      cmd.trim();

      if (cmd.startsWith("V ")) {
        int space_idx = cmd.indexOf(' ', 2);
        if (space_idx > 0) {
          target_speed_X = cmd.substring(2, space_idx).toInt();
          target_speed_Y = cmd.substring(space_idx + 1).toInt();
          driverX.rms_current(800, 0.0); // Restaura torque total
          digitalWrite(X_EN_PIN, LOW);
          digitalWrite(Y_EN_PIN, LOW);
          is_moving = true;
          manual_mode = false;
          safety_stop_triggered = false;
        }
      } else if (cmd.startsWith("T") || cmd.startsWith("t")) {
        int space_idx = cmd.indexOf(' ');
        target_speed_Y =
            (space_idx > 0) ? cmd.substring(space_idx + 1).toInt() : 2000;
        target_speed_X =
            -50; // Tenta puxar o filme de volta bem devagar (tensionador)
        driverX.rms_current(150,
                            0.0); // Força super macia (Freio eletromagnético)
        digitalWrite(X_EN_PIN, LOW); // Liga o X
        digitalWrite(Y_EN_PIN, LOW); // Liga o Y
        is_moving = true;
        manual_mode = false; // Modo PID rápido!
        safety_stop_triggered = false;
      } else if (cmd.startsWith("F") || cmd.startsWith("f")) {
        int space_idx = cmd.indexOf(' ');
        target_speed_Y =
            (space_idx > 0) ? cmd.substring(space_idx + 1).toInt() : 2000;
        target_speed_X = 0;
        driverX.rms_current(800, 0.0); // Restaura torque
        digitalWrite(X_EN_PIN, HIGH);
        digitalWrite(Y_EN_PIN, LOW);
        is_moving = true;
        manual_mode = true;
        safety_stop_triggered = false;
      } else if (cmd.startsWith("R") || cmd.startsWith("r")) {
        int space_idx = cmd.indexOf(' ');
        long spd =
            (space_idx > 0) ? cmd.substring(space_idx + 1).toInt() : 2000;
        target_speed_X = -spd;
        target_speed_Y = 0;
        driverX.rms_current(800, 0.0); // Restaura torque
        digitalWrite(Y_EN_PIN, HIGH);
        digitalWrite(X_EN_PIN, LOW);
        is_moving = true;
        manual_mode = true;
        safety_stop_triggered = false;
      } else if (cmd.startsWith("U") || cmd.startsWith("u")) {
        int space_idx = cmd.indexOf(' ');
        target_speed_Y = (space_idx > 0) ? cmd.substring(space_idx + 1).toInt() : 2000;
        // APENAS ATUALIZA A VELOCIDADE! Sem UART block! Sem mexer nos pinos EN!
      } else if (cmd.startsWith("Z") || cmd.startsWith("z")) {
        int space_idx = cmd.indexOf(' ');
        long spd = (space_idx > 0) ? cmd.substring(space_idx + 1).toInt() : 0;
        target_speed_Z = spd;
        if (spd == 0) {
            digitalWrite(Z_EN_PIN, HIGH); // Desliga motor Z
        } else {
            digitalWrite(Z_EN_PIN, LOW);  // Liga motor Z
            is_moving = true;
        }
      } else if (cmd.startsWith("L") || cmd.startsWith("l")) {
        int space_idx = cmd.indexOf(' ');
        long brightness = (space_idx > 0) ? cmd.substring(space_idx + 1).toInt() : 0;
        brightness = max(0L, min(255L, brightness));
        
        if (brightness == 255) {
            digitalWrite(LED_PIN, HIGH); // Bypass total do PWM: Garante 100% de passagem
        } else if (brightness == 0) {
            digitalWrite(LED_PIN, LOW);  // 0%
        } else {
            analogWriteResolution(8);    // Força a resolução para 0-255
            analogWrite(LED_PIN, brightness);
        }
      } else if (cmd == "S" || cmd == "s") {
        driverX.rms_current(800, 0.0); // Restaura torque para travar o rolo
        digitalWrite(X_EN_PIN, LOW);
        digitalWrite(Y_EN_PIN, LOW);
        target_speed_X = 0;
        target_speed_Y = 0;
        target_speed_Z = 0;
        digitalWrite(Z_EN_PIN, HIGH); // Z desliga na parada de emergência
        Serial.println("Manobra: Parada Iniciada");
      }
    } else {
      cmd_buffer += c;
    }
  }
}

void loop() {
  parse_serial_command();

  if (safety_stop_triggered)
    return;

  // Envia a posição do encoder rotativo a cada 50ms para o Host (PID)
  static unsigned long last_encoder_report = 0;
  if (millis() - last_encoder_report >= 50) {
    last_encoder_report = millis();
    Serial.print("E ");
    Serial.println(encoder_pulses);
  }

  // --- LÓGICA DE RAMPA DE ACELERAÇÃO ---
  if (millis() - last_accel_time >= 10) {
    last_accel_time = millis();
    // Se estiver no PID, acelera rápido para não atrasar o controle matemático.
    // Se for manual, rampa suave de 0.5s.
    long accel_step =
        manual_mode ? 40 : 10000; // 40 Hz a cada 10ms = 2000 Hz em 0.5s

    // Eixo Y
    if (current_speed_Y < target_speed_Y) {
      current_speed_Y = min(current_speed_Y + accel_step, target_speed_Y);
    } else if (current_speed_Y > target_speed_Y) {
      current_speed_Y = max(current_speed_Y - accel_step, target_speed_Y);
    }

    // Eixo X
    if (current_speed_X < target_speed_X) {
      current_speed_X = min(current_speed_X + accel_step, target_speed_X);
    } else if (current_speed_X > target_speed_X) {
      current_speed_X = max(current_speed_X - accel_step, target_speed_X);
    }

    // Eixo Z
    if (current_speed_Z < target_speed_Z) {
      current_speed_Z = min(current_speed_Z + accel_step, target_speed_Z);
    } else if (current_speed_Z > target_speed_Z) {
      current_speed_Z = max(current_speed_Z - accel_step, target_speed_Z);
    }

    // Atualiza Direção fisicamente baseada no sinal da velocidade atual
    if (current_speed_X != 0)
      digitalWrite(X_DIR_PIN, (current_speed_X > 0) ? HIGH : LOW);
    if (current_speed_Y != 0)
      digitalWrite(Y_DIR_PIN, (current_speed_Y > 0) ? HIGH : LOW);
    if (current_speed_Z != 0)
      digitalWrite(Z_DIR_PIN, (current_speed_Z > 0) ? HIGH : LOW);

    // Recalcula os intervalos (Hz -> Microssegundos)
    step_interval_X =
        (current_speed_X != 0) ? 1000000UL / abs(current_speed_X) : 0;
    step_interval_Y =
        (current_speed_Y != 0) ? 1000000UL / abs(current_speed_Y) : 0;
    step_interval_Z =
        (current_speed_Z != 0) ? 1000000UL / abs(current_speed_Z) : 0;

    // Parada total
    if (current_speed_X == 0 && current_speed_Y == 0 && current_speed_Z == 0 && 
        target_speed_X == 0 && target_speed_Y == 0 && target_speed_Z == 0) {
      is_moving = false;
    }
  }

  unsigned long current_micros = micros();

  // Pulso Motor X
  if (is_moving && step_interval_X > 0) {
    if (current_micros - last_step_time_X >= step_interval_X) {
      last_step_time_X = current_micros;
      digitalWrite(X_STEP_PIN, HIGH);
      delayMicroseconds(2);
      digitalWrite(X_STEP_PIN, LOW);
    }
  }

  // Pulso Motor Y
  if (is_moving && step_interval_Y > 0) {
    if (current_micros - last_step_time_Y >= step_interval_Y) {
      last_step_time_Y = current_micros;
      digitalWrite(Y_STEP_PIN, HIGH);
      delayMicroseconds(2);
      digitalWrite(Y_STEP_PIN, LOW);
    }
  }

  // Pulso Motor Z
  if (is_moving && step_interval_Z > 0) {
    if (current_micros - last_step_time_Z >= step_interval_Z) {
      last_step_time_Z = current_micros;
      digitalWrite(Z_STEP_PIN, HIGH);
      delayMicroseconds(2);
      digitalWrite(Z_STEP_PIN, LOW);
    }
  }

  // Temporariamente desativado: O StallGuard precisa de calibração fina
  // baseada na nova corrente (100mA). Estava disparando falsos positivos.
  /*
  if (is_moving && (millis() - last_sg_check > 50)) {
      last_sg_check = millis();
      uint16_t sg_result = driverY.SG_RESULT();
      if (sg_result > 0 && sg_result < SG_THRESHOLD_Y) {
          is_moving = false;
          safety_stop_triggered = true;
          speed_X = 0; speed_Y = 0;
          Serial.print("!STALL! EMERGENCIA Y. SG=");
          Serial.println(sg_result);
      }
  }
  */
}

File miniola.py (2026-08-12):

import sys 
import platform
from unittest.mock import MagicMock

# --- CONFIGURAÇÃO DE AMBIENTE E HARDWARE ---
if platform.machine() not in ('aarch64', 'armv7l'):
    sys.modules["pykms"] = MagicMock()
    sys.modules["kms"] = MagicMock()

try:
    import miniola_cv  # type: ignore
    CV_ENGINE = "C++ [Pybind11]"
    scanner_cv = miniola_cv.ScannerVision()
except ImportError:
    CV_ENGINE = "Python [Nativo]"
    scanner_cv = None

from flask import Flask, Response, request, render_template, send_from_directory, jsonify  # type: ignore
import argparse
from cameras import get_camera_provider 
from core.motor_controller import FilmTransportPID
from core.joystick import GamepadController
import cv2 
import numpy as np 
import threading 
import multiprocessing as mp 
import time 
import logging 
import shutil
import os
import subprocess
import glob
import json
from datetime import datetime, timezone
try:
    from PIL import Image as PILImage
    HAS_PIL = True
except ImportError:
    HAS_PIL = False
    PILImage = None  # type: ignore

app = Flask(__name__) # Flask para o Dashboard (Roda no Core 0)
log = logging.getLogger('werkzeug') # Desativa os logs de requisição do Flask para não poluir o console
log.setLevel(logging.ERROR) 

CAPTURE_PATH = "capturas"
if not os.path.exists(CAPTURE_PATH): os.makedirs(CAPTURE_PATH)

# Parser de Argumentos
parser = argparse.ArgumentParser(description="Miniola - Digitalizador e Metrologia de Películas")
parser.add_argument('--camera', type=str, default='ximea', choices=['pi', 'ximea', 'uvc', 'mock'], help='Provedor de câmera a utilizar')
parser.add_argument('--ximea-mode', type=str, default='raw', choices=['raw', 'rgb'], help='Modo de cor interno para Ximea (ISP ligado = rgb)')
args = parser.parse_args()

CAMERA_MODE = args.camera

# Controle de Motores (SKR Pico)
motor = FilmTransportPID()
motor.connect()

def toggle_rec():
    global GRAVANDO, fila_gravacao, ultimo_pitch_medio, PITCH_PADRAO_PX, AUDIO_CAPTURE_ENABLED, FPS_PROJECAO, fps_motor
    if not GRAVANDO:
        motor.start_pid(target_fps=fps_motor)
        sid = datetime.now(timezone.utc).strftime("%Y%m%dT%H%M%SZ")
        try:
            p_val = ultimo_pitch_medio if ultimo_pitch_medio > 0 else PITCH_PADRAO_PX
            fila_gravacao.put({
                "type": "rec_start", "session_id": sid,
                "audio_enabled": AUDIO_CAPTURE_ENABLED, "fps_projecao": FPS_PROJECAO,
                "pitch_padrao": p_val
            }, block=True, timeout=2)
        except Exception as e: 
            print(f"[ERRO] Falha ao iniciar REC: {e}")
            return
        GRAVANDO = True
        print(f"\n[SISTEMA] REC ON | Sessão: {sid}\n>> ", end="", flush=True)
    else:
        GRAVANDO = False
        motor.stop_pid()
        motor.stop()
        try: fila_gravacao.put({"type": "rec_stop"}, block=True, timeout=2)
        except Exception as e: print(f"[WARN] REC OFF sem confirmação: {e}")
        print("\n[SISTEMA] REC OFF\n>> ", end="", flush=True)

gamepad = GamepadController(motor, on_rec_toggle=toggle_rec)
gamepad.start()

shutter_speed, gain, fps_cam = 1000, 1.0, 80
fps_motor = 18.0
foco_atual, passo_foco = 14.5, 0.5


# Resolução: Corte de Hardware para aliviar a porta USB do Raspberry Pi 4
# Largura 1420 acomoda a imagem (1388) e Altura 880 acomoda a ROI (840).
# Redução de 32% no tráfego de dados!
RES_W, RES_H = 1420, 880

# Offsets Exatos do CamTool do Usuário
CAM_OFFSET_X = 272
CAM_OFFSET_Y = 224

# --- SOFTWARE ISP (LUT) ---
WB_R, WB_G, WB_B = 1.0, 1.0, 1.0
GAMMA_Y, GAMMA_C = 1.0, 1.0
CONTRAST = 0.0

def build_color_lut(r, g, b, gy, gc, contrast):
    """Constrói a tabela de pré-computação (LUT) do ISP para o OpenCV aplicar instantaneamente"""
    lut = np.zeros((1, 256, 3), dtype=np.uint8)
    f_c = (259 * (contrast + 255)) / (255 * (259 - contrast)) if contrast != 0 else 1.0
    for i in range(256):
        val = i / 255.0
        # Gamma simples
        g_val = val ** (1.0 / gy) if gy > 0 else val
        # WB multipliers
        b_val, g_val, r_val = g_val * b, g_val * g, g_val * r
        # Re-scale e Contrast
        b_idx = f_c * (b_val * 255 - 128) + 128
        g_idx = f_c * (g_val * 255 - 128) + 128
        r_idx = f_c * (r_val * 255 - 128) + 128
        # Store in LUT (OpenCV usa BGR)
        lut[0, i, 0] = np.clip(b_idx, 0, 255)
        lut[0, i, 1] = np.clip(g_idx, 0, 255)
        lut[0, i, 2] = np.clip(r_idx, 0, 255)
    return lut

PIPELINE_LUT = build_color_lut(WB_R, WB_G, WB_B, GAMMA_Y, GAMMA_C, CONTRAST)

print(f"[SISTEMA] Inicializando provedor de câmera: {args.camera.upper()}")
camera = get_camera_provider(args.camera)
if args.camera == 'ximea':
    camera.start(RES_W, RES_H, fps_cam, shutter_speed, gain, foco_atual, CAM_OFFSET_X, CAM_OFFSET_Y, color_mode=args.ximea_mode)
else:
    camera.start(RES_W, RES_H, fps_cam, shutter_speed, gain, foco_atual, CAM_OFFSET_X, CAM_OFFSET_Y)

# Padrão Bayer Padrão (Pode ser alterado dinamicamente via painel)
# Mudando para RG2BGR porque o crop no sensor altera o alinhamento da matriz Bayer, causando a imagem rosa!
BAYER_MODE = cv2.COLOR_BayerBG2BGR

# --- GEOMETRIA DO ROI E ESTADO ---
GRAVANDO = False
PLAYBACK_MODE = False        # Visão em tempo real (PLL)
CALIBRANDO = False           # Trava de segurança da tela
PROCESSANDO_VIDEO = False    # Alerta o scanner para hibernar

FPS_PROJECAO = 24.0          # FPS de reprodução do filme (independente do fps_cam do sensor!)
ROI_X, ROI_Y = 200, 10
ROI_W, ROI_H = 80, 840
# --- LÓGICA DE GATILHO SIMPLIFICADA ---
LINHA_GATILHO_Y = 110  # Posição Y relativa DENTRO da ROI
MARGEM_GATILHO = 23    # Margem de disparo (px para cima e para baixo)
THRESH_VAL = 239 # Valor do threshold para binarização
PITCH_PADRAO_PX = 195.0  # CALIBRE AQUI: Quantos pixels tem o pitch de um filme NOVO na sua lente?
# --- PARÂMETROS DO CROP ---
OFFSET_X = 470 
OFFSET_Y_CROP = 0 # Deslocamento Y relativo à âncora (linha de gatilho)
CROP_W, CROP_H = 918, 612 

# --- EXTRAÇÃO DE ÁUDIO ÓTICO (CAPTURA AO VIVO) ---
AUDIO_X_OFFSET = 50      # Distância da borda direita da ROI perfuração até a pista de som
AUDIO_CAPTURE_ENABLED = True
AUDIO_CAPTURE_MODE = "variable_density"
AUDIO_READ_W = 96


contador_perfs_ciclo = 0
frame_count = 0
perfuracao_na_linha = False
ultimo_frame_bruto = None
ultimo_frame_binario = None
ultimo_crop_preview = np.zeros((CROP_H, CROP_W, 3), dtype=np.uint8)
lista_contornos_debug = []
fps_real_proc = 0.0
tempo_ms_ciclo = 0.0
encolhimento_atual_pct = 0.0

# --- FILA DE MULTIPROCESSAMENTO ---
fila_gravacao = mp.Queue(maxsize=30) 
ultimo_pitch_medio = 0.0
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

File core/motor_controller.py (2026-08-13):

import serial
import threading
import time
import logging

class FilmTransportPID:
    GAUGES = {
        '35mm': {'pitch': 4.75},
        '16mm': {'pitch': 7.62},
        '8mm': {'pitch': 3.81},
        'super8': {'pitch': 4.23}
    }

    def __init__(self, port='/dev/ttyACM0', baudrate=115200, gauge='35mm'):
        self.port = port
        self.baudrate = baudrate
        self.serial = None
        self.connected = False
        
        # Parâmetros Mecânicos e Estado
        self.gauge = gauge
        self.pitch = self.GAUGES.get(gauge, self.GAUGES['35mm'])['pitch']
        self.target_fps = 18.0
        self.target_mm_s = self.target_fps * self.pitch
        self.current_mm_s = 0.0
        
        # Setup do Encoder e Rolete
        self.roller_diameter = 26.6
        self.roller_circumference = 3.14159 * self.roller_diameter
        # O Encoder E38S6G5 tem 600 PPR, mas o RP2040 lê em quadratura completa (4 bordas por pulso)
        self.encoder_ppr = 2400.0
        self.last_encoder_pulses = 0
        self.last_encoder_time = 0.0
        self.encoder_distance_accumulated = 0.0 # Distância percorrida desde a última perfuração vista
        
        # Ganhos do PID (Otimizados para suavidade extrema baseada em Feed-Forward)
        self.Kp = 0.1   # Quase zero! Ignora oscilações rápidas (Jitter da USB)
        self.Ki = 1.5   # Memória que corrige a variação lenta do diâmetro do rolo
        self.Kd = 0.0   # ZERO! A derivada com encoder via USB gera ruído brutal
        
        self.smoothed_adjustment = 0.0
        self.encoder_history = [] # Janela deslizante para cálculo de velocidade
        
        # PLL (Phase-Locked Loop)
        self.phase_error_mm = 0.0
        self.Kp_phase = 2.5 # Ganho de correção de fase (mm/s por mm de erro)
        
        self.error_sum = 0.0
        self.last_error = 0.0
        self.last_pid_time = time.time()
        
        # Velocidade Base Inicial (Passos por segundo - Hz)
        self.base_speed_y = 1000 # Take-up puxa
        self.base_speed_x = 200  # Feed-in segura levemente (tensão passiva)
        
        self.is_running_pid = False
        self.thread = None
        self.lock = threading.Lock()

    def connect(self):
        try:
            self.serial = serial.Serial(self.port, self.baudrate, timeout=0.1)
            self.connected = True
            logging.info(f"Conectado à SKR Pico em {self.port}")
            return True
        except serial.SerialException as e:
            logging.error(f"Erro ao conectar na placa SKR Pico: {e}")
            self.connected = False
            return False

    def disconnect(self):
        self.stop()
        if self.serial and self.serial.is_open:
            self.serial.close()
        self.connected = False

    def send_command(self, cmd: str):
        if self.connected and self.serial.is_open:
            try:
                self.serial.write((cmd + '\n').encode('utf-8'))
            except Exception as e:
                logging.error(f"Erro de escrita serial: {e}")

    # --- CONTROLES MANUAIS (Acionamento independente do PID) ---
    def manual_forward(self, speed=2000):
        self.stop_pid()
        self.send_command(f"F {speed}")

    def manual_reverse(self, speed=2000):
        self.stop_pid()
        self.send_command(f"R {speed}")

    def stop(self):
        self.stop_pid()
        self.send_command("S")

    # --- CONTROLE DE FOCO (Atuador Z) ---
    def focus_in(self, speed=500):
        self.send_command(f"Z {speed}")

    def focus_out(self, speed=500):
        self.send_command(f"Z -{speed}")

    def focus_stop(self):
        self.send_command("Z 0")

    # --- CONTROLE DE ILUMINAÇÃO (Painel LED) ---
    def set_led_brightness(self, level: int):
        level = max(0, min(255, int(level)))
        self.send_command(f"L {level}")

    # --- SINCRONIA ÓPTICA (Híbrida - SPEC-011) ---
    def sync_optical_phase(self):
        """
        Chamado pelo OpenCV quando uma perfuração válida cruza a linha de gatilho perfeitamente.
        Isso zera a distância mecânica acumulada, atrelando a fase física à fase óptica.
        """
        with self.lock:
            self.encoder_distance_accumulated = 0.0

    def get_accumulated_distance(self):
        """
        Retorna quantos milímetros o filme andou desde o último furo lido pela câmera.
        Usado pelo orquestrador para forçar a captura se o OpenCV falhar (Dead-Reckoning).
        """
        with self.lock:
            return self.encoder_distance_accumulated

    def update_phase_error(self, error_px: float, pixels_per_mm: float):
        """
        Recebe o erro de fase (distância do furo detectado até a linha de gatilho).
        Atualiza o Phase-Locked Loop.
        """
        if pixels_per_mm > 0:
            with self.lock:
                self.phase_error_mm = error_px / pixels_per_mm
    # --- LOOP PID (Mola Matemática) ---
    def start_pid(self, target_fps=None):
        if not self.connected:
            return
        
        self.is_running_pid = True
        self.error_sum = 0.0
        self.last_error = 0.0
        
        # Usa o FPS passado (ex: da câmera) ou o default 18.0
        _fps = target_fps if target_fps is not None else self.target_fps
        # No 35mm, 1 Frame = 4 furos. Logo, a velocidade física (mm/s) tem que ser multiplicada por 4!
        self.target_mm_s = _fps * (self.pitch * 4) 
        
        self.ramped_target = 0.0 # Começa do zero (Soft Start)
        self.current_mm_s = 0.0
        self.smoothed_adjustment = 0.0
        
        self.last_sent_speed = None # Gatilho para o primeiro comando F
        self.last_encoder_time = time.time()
        self.pid_start_time = time.time() # Para calcular a curva S de aceleração
        self.last_encoder_pulses = 0
        self.encoder_history = []
        
        self.thread = threading.Thread(target=self._pid_loop, daemon=True)
        self.thread.start()

    def stop_pid(self):
        if self.is_running_pid:
            self.is_running_pid = False
            if hasattr(self, 'thread') and self.thread is not None:
                if threading.current_thread() != self.thread:
                    self.thread.join(timeout=0.5)
            self.send_command("S")
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

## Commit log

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2026-02-05 diminuir tempo de exposição, aumento do ganho para 5 e treshold para 170
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2026-02-05 fix: substitui threshold adaptativo por binário com blur para reduzir falsos positivos
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2026-02-21 Revert "teste de foco"
    This reverts commit 47909381f8fff21c3ad355825e7740efe3d3f341.
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2026-02-28 refactor miniola.py: streamline code structure and enhance camera configuration for improved performance
2026-02-28 refactor miniola.py: improve control panel commands and streamline camera configuration for enhanced usability
2026-03-01 refactor miniola.py: improve logging configuration, streamline camera initialization, and enhance control panel commands for better usability
2026-03-01 refactor miniola.py: update camera initialization, enhance control panel commands, and improve logging configuration for better usability
2026-03-01 refactor miniola.py: optimize camera settings, add preview feed route, and enhance control panel interface for improved usability
2026-03-01 refactor miniola.py: update comments for clarity, optimize initial values for stability, and adjust JPEG quality for better performance
    [miniola.py]
2026-03-01 refactor miniola.py: optimize initial values for stability, adjust ROI height for better detection, and improve JPEG quality for performance
    [miniola.py]
2026-03-01 refactor miniola.py: enhance noise filter parameters for improved detection accuracy
    [miniola.py]
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2026-03-01 refactor miniola.py: reset ROI_X and ROI_Y positions for improved dynamic geometry
    [miniola.py]
2026-03-01 refactor miniola.py: correct ROI_X position for improved dynamic geometry
    [miniola.py]
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2026-03-11 Ajuste de controle de foco na câmera: adicionado suporte para ajuste de foco por gradações e comandos no painel de controle.
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2026-03-15 Corrige o caminho de captura para o diretório correto no sistema Miniola
    [miniola.py]
2026-03-15 Add initial README documentation for Miniola project
    Adiciona documentação inicial sobre o Miniola, incluindo arquitetura, guia de instalação e operação.
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2026-03-19 Refactor miniola_debug.py for improved readability and functionality; added headless mock for pykms, updated control panel messages, and optimized frame processing logic.
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2026-03-20 Revert hardware configuration to 800x600 and adjust crop dimensions for consistency in miniola.py
    [miniola.py]
2026-03-21 Refactor miniola_debug.py: Adjust safety margin for pitch tracking logic to improve accuracy
2026-03-22 Refactor miniola_debug.py: Update frame rate configuration and enhance control panel to include FPS adjustments for improved performance monitoring
2026-03-22 Refactor miniola_debug.py: Optimize disk writing thread and improve image processing efficiency in capture function
2026-03-23 Refactor miniola_debug.py: Increase the number of frames in preview feed from 48 to 120 for enhanced image display and add thread for disk writing
2026-03-24 Refactor miniola_debug.py: Optimize hole detection logic to calculate center coordinates based on visible holes and reset cycle after every four detections
2026-03-24 Refactor miniola_debug.py: Adjust frame rate from 90 to 60 for improved performance and update comments for clarity
2026-03-24 Refactor miniola_debug.py: Update control panel print statements for clarity and add new commands for crop and ROI adjustments
2026-03-25 Refactor miniola_debug.py: Adjust camera settings and ROI parameters for improved image capture and processing
2026-03-25 Refactor miniola_debug.py: Update camera frame rate, threshold value, and crop offset; add telemetry variables to status endpoint
2026-03-25 Refactor miniola_debug.py: Add CPU temperature reading to status endpoint and update UI to display temperature
2026-03-26 Refactor miniola_debug.py: Optimize scanner logic with isolated motors for improved detection accuracy
2026-03-26 Refactor miniola_debug.py: Enhance 2D detection logic for improved speed and stability with optimized area calculations and valid hole tracking
2026-03-28 Refactor miniola_debug.py: Enhance stability logic in scanner with improved multi-point projection and pitch calculations
2026-03-30 Refactor miniola_debug.py: Add calibration route and enhance drawing functionality for improved optical calibration
2026-03-30 Refactor miniola_debug.py: Enhance canvas functionality with improved drawing logic and calibration integration
2026-03-30 Refactor miniola_debug.py: Add calibration mode activation and safe shutdown command to control panel
2026-03-30 Refactor miniola_debug.py: Implement static shrinkage calculation with a buffer for pitch samples
2026-03-30 Refactor miniola_debug.py: Add dynamic calibration feature for pitch measurement and update buffer logic
2026-03-30 Implement feature X to enhance user experience and fix bug Y in module Z
    [miniola.py]
2026-03-30 Fix display label for preservation shrinkage in index view and update start script to launch miniola.py
    [miniola.py]
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2026-03-31 Update video configuration to use YUV420 format for low-resolution stream and optimize frame processing logic
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2026-03-31 Optimize scanner logic by reducing memory usage and improving performance in frame processing
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2026-03-31 Adjust frame rate to 50 FPS and update resolution handling for 16:9 aspect ratio
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2026-03-31 Fix frame conversion in scanner logic to use main frame instead of low-resolution frame
    [miniola.py]
2026-03-31 Enhance trigger logic to include pitch calculation and improve frame capture accuracy
2026-03-31 Refactor camera settings and optimize scanner logic for improved performance and reliability
2026-03-31 Fix binary frame initialization to use correct width for improved processing
    [miniola.py]
2026-03-31 feat: Implement miniola_debug.py for camera control and image processing
    - Added Flask web server for dashboard interface.
    - Integrated Picamera2 for camera management and image capture.
    - Implemented multi-threading and multiprocessing for efficient image processing and saving.
    - Introduced ROI (Region of Interest) settings for targeted image analysis.
    - Added calibration features for optical measurements and autofocus capabilities.
    - Included real-time status updates and image previews in the web interface.
    - Implemented logging and error handling for improved stability.
    [miniola.py, process.py]
2026-04-01 feat: implement C++ OpenCV vision engine via pybind11 for optimized frame processing
2026-04-01 feat: implement high-performance computer vision processing using C++ and Pybind11 with cycle reset support
    [miniola.py]
2026-04-01 refactor: move index template to file and implement frame gap compensation in concat manifest
2026-04-01 refactor: replace EMA with sliding window average for more accurate telemetry calculation
    [miniola.py]
2026-04-01 fix: add error handling and output logging for FFmpeg process failures
    [miniola.py]
2026-04-01 fix: update AEO_SYNC_INFO metadata header prefix from semicolon to hash
    [process.py]
2026-04-01 refactor: lock camera resolution to HIGH, update FPS, and simplify command interface
2026-04-02 refactor: switch camera format to YUV420 and optimize frame processing to use grayscale luminance data
2026-04-02 feat: implement ScannerVision class with OpenCV and pybind11 for real-time hole detection and shrinkage analysis
2026-04-02 fix: update video configuration format to lowercase yuv420 for compatibility
    [miniola.py]
2026-04-02 legacy do miniola.py antes do bug do YUV e o legacy do index.html
    [miniola.py]
2026-04-02 refactor: improve optical audio extraction with Otsu thresholding, temporal smoothing, and band-pass filtering
2026-04-02 legacy: simplify audio extraction logic by removing complex filtering and debug features
2026-04-04 feat: use calculated pitch for sample rate and frame calculations instead of default constant
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2026-04-05 feat: implement audio mastering pipeline with filtering and normalization, and clean up console output logs
2026-04-05 feat: implement dynamic weave tracker to adjust audio window offset based on optical track luminosity
2026-04-05 refactor: constrain optical track search area and add outlier rejection to stabilize audio offset tracking
    [miniola.py]
2026-04-05 feat: implement ScannerVision class with OpenCV-based frame processing and spatial audio line-scanning logic
2026-04-05 feat: add stationary noise reduction using spectral gating via noisereduce library
    [process.py]
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2026-04-07 fix: disable 90Hz notch filter and reduce noise reduction intensity in audio processing
    [process.py]
2026-04-08 feat: apply median filtering to audio signal to reduce noise artifacts
    [process.py]
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2026-04-08 feat: increase noise reduction intensity and add audio capture mode configuration to control panel
    [miniola.py, process.py]
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2026-04-09 refactor: adjust noise reduction intensity and update audio capture calibration parameters
    [miniola.py, process.py]
2026-04-10 feat: improve audio processing by adding median filtering, raising cutoff frequency, and switching to stationary noise reduction
    [process.py]
2026-04-12 fix: increase noise reduction prop_decrease to 0.5 for more effective filtering
    [process.py]
2026-04-12 fix: increase noise reduction prop_decrease to 0.8 for better signal processing
    [process.py]
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2026-04-12 fix: disable stationary mode in noise reduction to improve audio processing quality
    [process.py]
2026-04-12 feat: implement C++ optical audio scanner and optimize noise reduction parameters in process.py
    [process.py]
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2026-04-26 chore: add type ignore suppressions for missing third-party module imports
    [miniola.py, process.py]
2026-04-26 fix: correct color space handling by standardizing on BGR capture and conversion for PIL-based output
    [miniola.py]
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2026-04-27 feat: implement optical tracking and sub-pixel stabilized video rendering via FFmpeg pipe
    [miniola.py, process.py]
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2026-05-02 Fix filename in Ximea camera SDK installation steps
    Corrected the filename in the installation instructions for the Ximea camera SDK.
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2026-05-02 fix: add support for grayscale images in audio strip processing to prevent conversion errors
    [miniola.py]
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2026-05-02 fix: correct debayering order for raw frames to prevent color data corruption during resizing
    [miniola.py]
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2026-05-02 feat: implement dynamic Bayer mode synchronization and refactor camera output visualization to use a consistent canvas with corrected aspect ratios.
    [miniola.py]
2026-05-02 fix: adjust audio preview width and slice coordinates in p_bin frame buffer
    [miniola.py]
2026-05-02 refactor: standardize p_live frame dimensions to 420x640 to prevent layout inconsistencies
    [miniola.py]
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2026-05-03 fix: resolve H.264 encoding crash by forcing even dimensions and correct queue destination for bayer settings
    [miniola.py]
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2026-07-19 Fix typos and update Raspberry Pi version
    Corrected typos and updated hardware specifications.
2026-07-19 docs: update README with multi-platform guide and Spec-Driven Development workflow, add required dependencies, and fix C++ compilation warnings.
    [check_specs.py]
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2026-08-02 feat: add dual-motor support, StallGuard monitoring, and optimized frame buffer handling for Ximea cameras
    [braco_motor-Corpo.step, braco_motor.FCStd]
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2026-08-09 feat: implement motor controller with PID speed regulation and slip detection for film transport
    [motor_controller.py]
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2026-08-09 feat: implement Ximea camera support and enforce even-coordinate cropping to fix Bayer pattern inversion
    [miniola.py, ximea.py]
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2026-08-09 fix: update LUT dimensions to 1x256 and adjust Bayer conversion mode for correct image alignment
    [miniola.py]
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2026-08-09 feat: add MotorController with PID-based film transport control and slip detection
    [motor_controller.py]
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
